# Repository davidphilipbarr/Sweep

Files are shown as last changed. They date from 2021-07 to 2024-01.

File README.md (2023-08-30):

# Sweep
<!--
           ___                        ___
      ___ |   | ___ ___      ___ ___ |   | ___
 ___ |   |`___`|   |   |    |   |   |`___`|   | ___
|   |`___`|   |`___`___`    `___`___`|   |`___`|   |
`___`|   |`___`|   |   |    |   |   |`___`|   |`___`
|   |`___`|   |`___`___`    `___`___`|   |`___`|   |
`___`|   |`___`|   |   |    |   |   |`___`|   |`___`
|   |`___`     `___`___`    `___`___`     `___`|   |
`___`           ___ ___      ___ ___           `___`
               |   |   |    |   |   |
               `___`___`    `___`___`
-->
>  sweep-hero  
> <sub>Bluetooth Sweep 2 + MBK Legend Keycaps</sub>

<span>
  <a href="https://discord.gg/czXcTXbsgU">
    
  </a>
  
  
  
</span>

## What is sweep?

Sweep is a version of the more fabulous [Ferris](https://github.com/pierrechevalier83/ferris) by [Pierre Chevalier](https://github.com/pierrechevalier83/) that uses a daughter board like a promicro, elite-c, bit-c, nice!nano etc. instead of using onboard components.

## What are the different types?

⭐ Sweep 2 - Recommended Choc v1 board with all the features.  
⭕ Sweep Half Swept - Same as Sweep 2, but with a reversible pro-micro footprint.  
⭕ Sweep Bling MX - An MX only Sweep that features Kailh's hotswap sockets and a stacked case.  
⭕ Sweep Bling LP - A Choc v1 only Sweep that features Kailh's hotswap sockets.  
⭕ Sweep High - Same as the Sweep 2, but trades choc spacing for compatibility with more switches and keycaps.  
⭕ Sweep High M - A soldered MX only Sweep, with a reversible PCB design.  
⭕ Sweep Mini - The only version that supports Choc minis.  

| Device | On/Off Switch<sup>[1]</sup> | Reversible PCB<sup>[2]</sup> | Choc V1 | Choc V2 | Choc Mini | MX & Alps | Choc Spacing<sup>[3]</sup> | Tenting<sup>[4]</sup> | Hot Swap |
| :--- | :---: | :---: | :---: | :---: | :---: | :---: | :---: | :---: | :---: |
| Sweep2.x | ✔ | | ✔ | | | | ✔ | ✔ | Mill-Max (optional) |
| Sweep Bling LP | ✔ | | ✔ | | | | ✔ | ✔ | Kailh (required) |
| Sweep Bling MX | ✔ | ✔ | | | | ⚠<br/><sup>[5]</sup> | | ✔ | Kailh (required) |
| Sweep High | ✔ | | ✔ | ✔ | | ✔ | | ✔ |
| Sweep High M | ✔ | ✔ | | | | MX | | ✔ | |
| Sweep Half Swept  | ✔ | ✔ | ✔ | | | | ✔ | ✔ | Mill-Max (optional) |
| Sweep Mini | | ✔ | | | ✔ | | ✔ | |

> Note: All versions support bluetooth with Nice!Nano

*<sup>[1]</sup> An on/off switch is recommended for bluetooth builds.*  
*<sup>[2]</sup> With a reversible PCB it's easier to make mistakes during assembly, but it allows you to purchase less boards.*  
*<sup>[3]</sup> Choc spaced boards have the switches in a tighter grid. This provides a better final look but is only compatible with some choc keycaps. (e.g. MBK)*  
*<sup>[4]</sup> Supports splitkb's [tenting puck.](https://splitkb.com/products/tenting-puck?_pos=1&_psq=tenting%20&_ss=e&_v=1.0)*  
*<sup>[5]</sup> MX + kailh hotswap ONLY. Alps are NOT supported.*  

## Components list

To build and use a Sweep you will need:

* 1x PCB Kit
* 2x promicro compatible boards or 2 nice!nanos.
* 34 switches of a compatible type (refer to the compatibility table)
* 34 keycaps
* 2x reset switches (optional; [B3U-1000P(M)](https://github.com/davidphilipbarr/Sweep/issues/20))
* Some little rubber feet/bumpers
* 2x power switches (optional if supported; MSK 12C02)
* 1x TRRS (not TRS!) cable (wired build only)
* 2x TRRS Jack [PJ-320A] (wired build only)
* 1 USB Cable (depends on your micro-controller choice)

## How do I make this thing?

<a href="https://www.youtube.com/watch?v=fBPu7AyDtkM" target="_blank">
  
</a>

## Firmware

The firmware can be found [with the Ferris  firmware as part of QMK](https://github.com/qmk/qmk_firmware/tree/master/keyboards/ferris/sweep).

Firmware for zmk and bluemicro_ble is called ["Cradio"](https://zmk.dev/docs/hardware/).

## Who made this?

* [Pierre Chevalier](https://github.com/pierrechevalier83)
* [David Barr](https://github.com/davidphilipbarr)
* [Ibnu Daru Aji](https://github.com/ibnuda/)
* [Duccio](https://github.com/duckyb)

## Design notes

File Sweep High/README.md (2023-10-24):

# Sweep HIGH
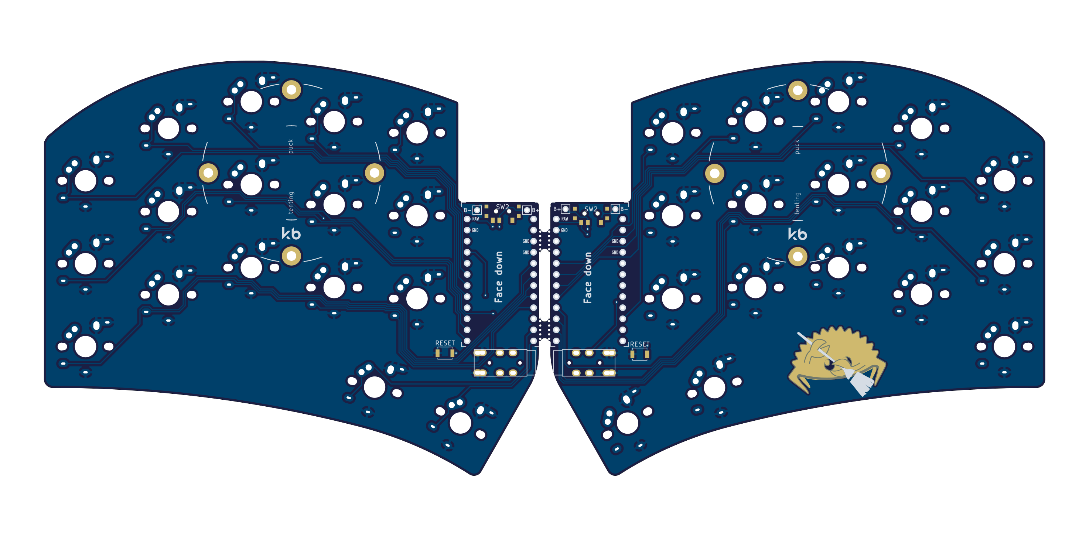
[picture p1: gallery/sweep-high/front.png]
front

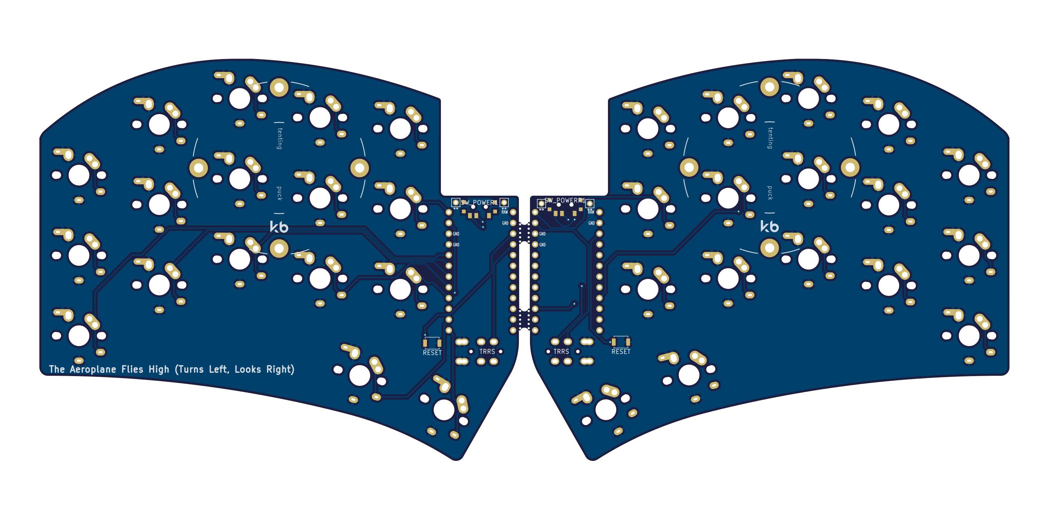
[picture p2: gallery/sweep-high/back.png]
back


Same as the Sweep2 but trades choc spacing for compatibility with more switches and keycaps.

## Ordering The PCB

To order the PCB the following settings are recommended<sup>1,2</sup>: 

|Detail|Value|
|---|---|
|Gerber file|`sweep-high_gerber.zip`|
|Base material|FR-4|
|Layers|2|
|Dimension|95.15mm x 229.54mm|
|Different design|2|
|Delivery format|Panel by customer|
|PCB thickness|1.6mm|
|PCB color|(Personal preference)|
|Silkscreen|(Personal preference)|
|Surface finish|(Personal preference)|
|Outer copper weight|1oz|
|Gold Fingers|No|
|Confirm production file|No|
|Castellated holes|No|
|Remove order number|Yes|

1: Settings are for [JLCPCB](https://jlcpcb.com/), but could work for other manufacturers.

2: Settings are taken from [Kyek's video guide](https://www.youtube.com/watch?v=fBPu7AyDtkM&t=17s).

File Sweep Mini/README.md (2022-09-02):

# Sweep Mini
| Front | Back |
| :---: | :---: |
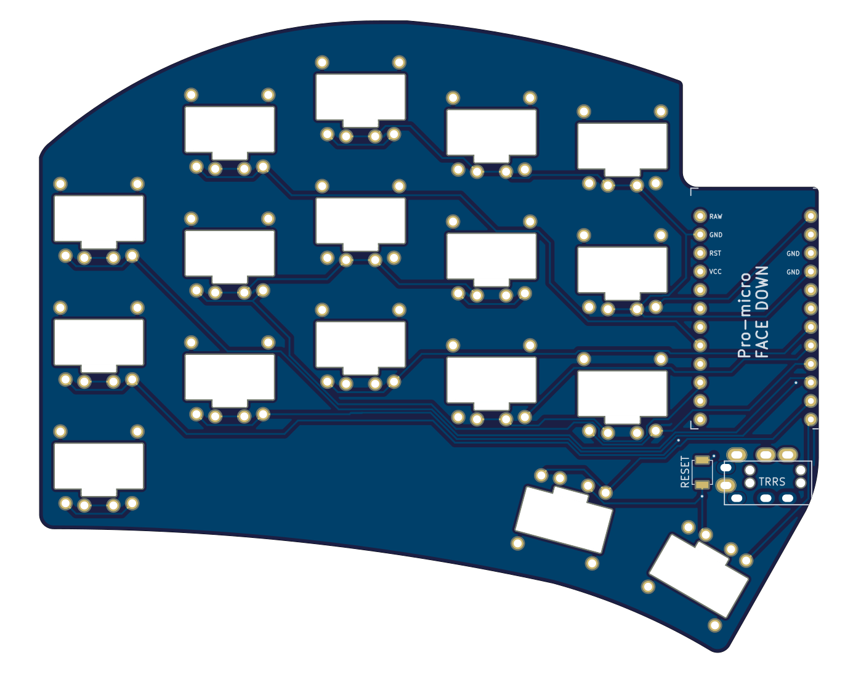
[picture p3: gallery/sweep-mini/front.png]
front
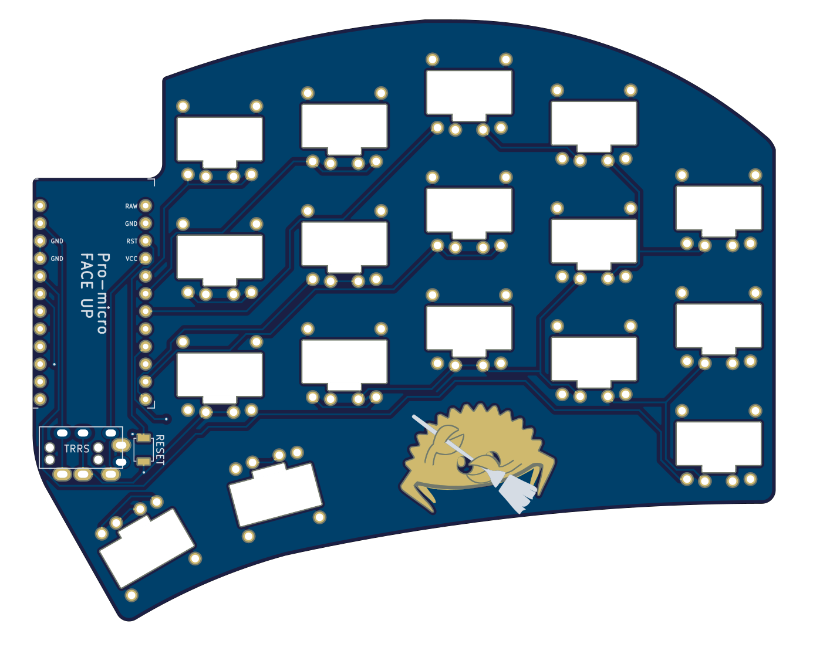
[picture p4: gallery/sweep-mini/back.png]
back
|  |  |

This is the only Sweep version that supports the "Choc Mini" switch.

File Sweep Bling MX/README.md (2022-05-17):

# Sweep Bling MX
| Front | Back |
| :---: | :---: |
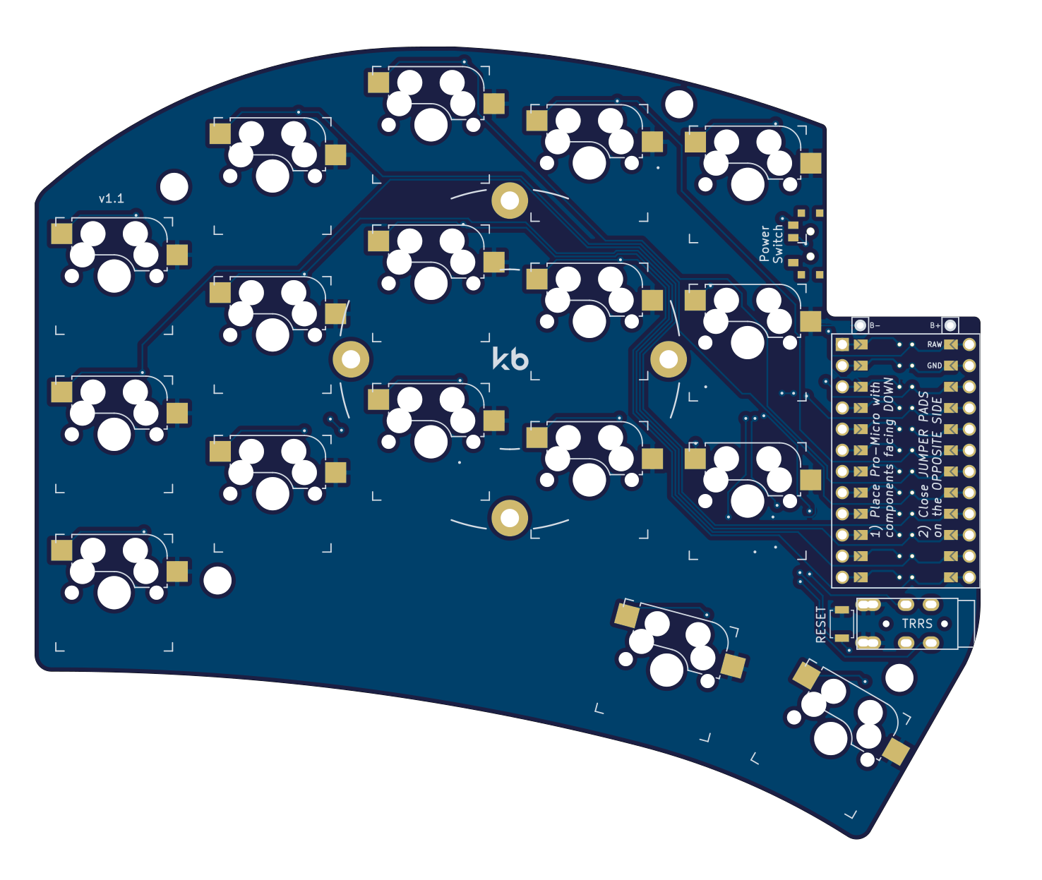
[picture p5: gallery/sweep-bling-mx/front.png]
front
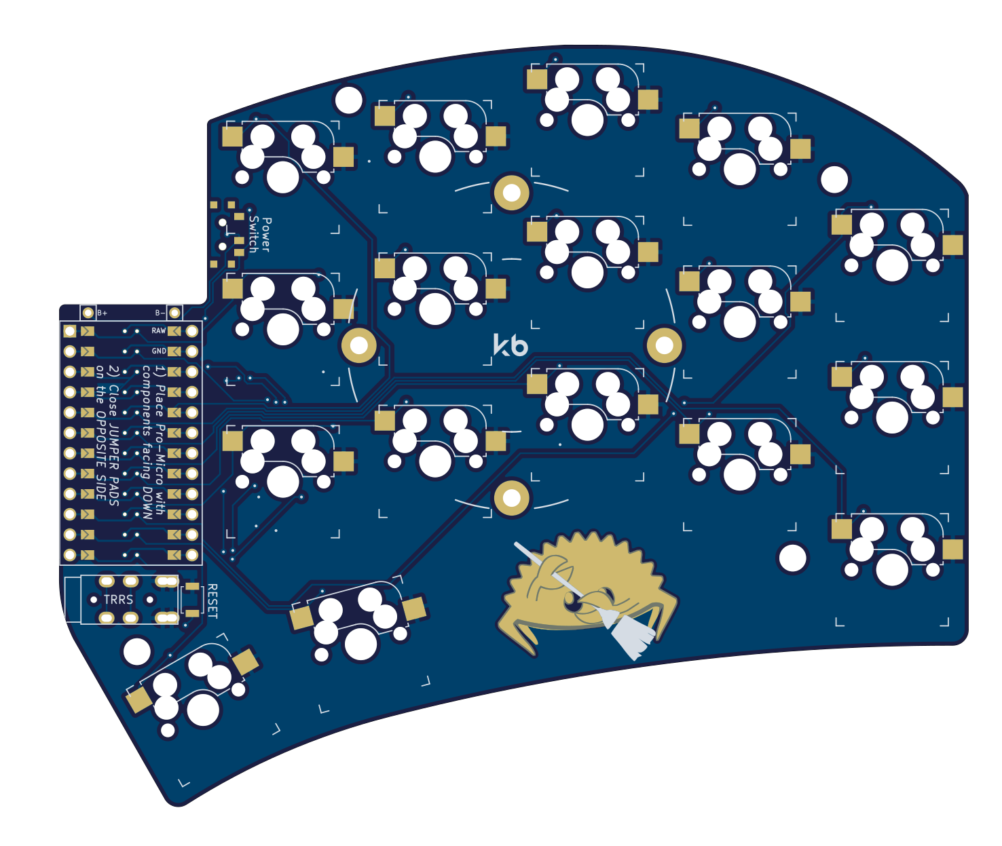
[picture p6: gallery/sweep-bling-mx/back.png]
back
|  |  |
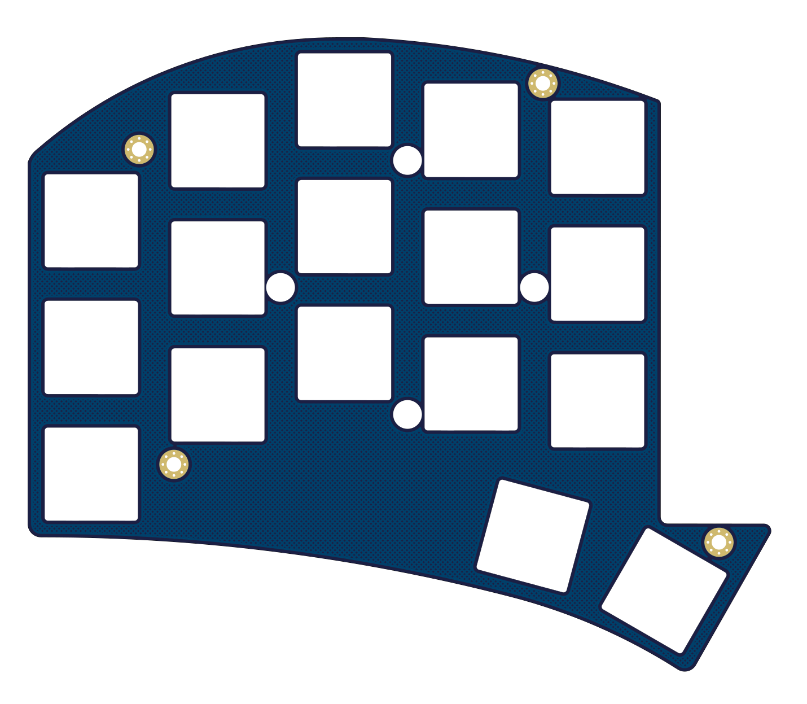
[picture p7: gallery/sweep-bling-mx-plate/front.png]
front
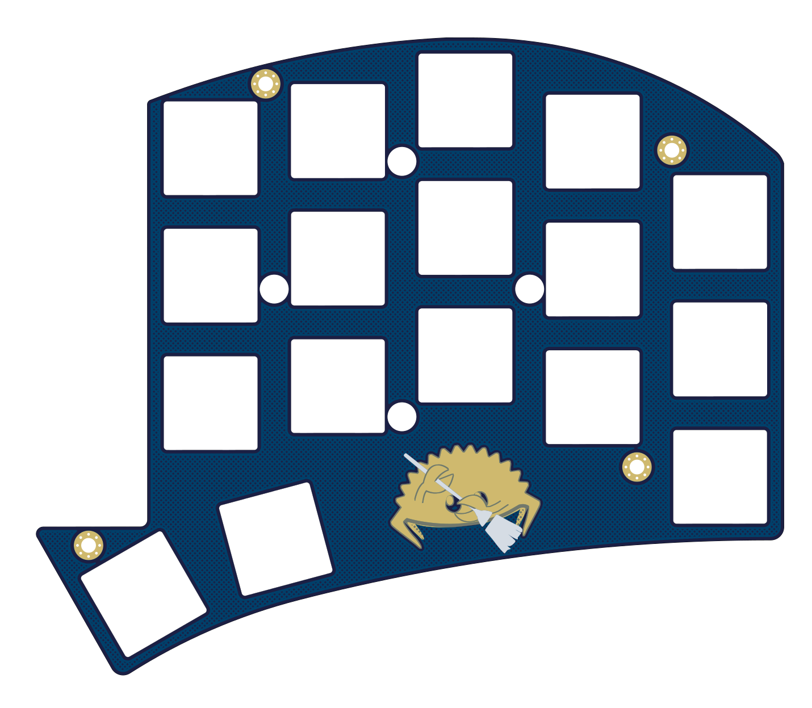
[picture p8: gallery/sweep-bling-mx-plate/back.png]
back
|  |  |
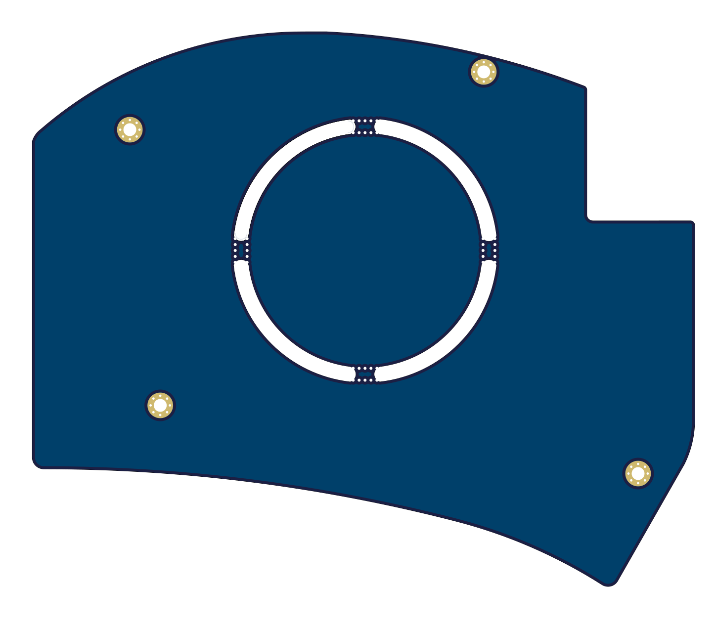
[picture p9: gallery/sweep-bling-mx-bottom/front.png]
front
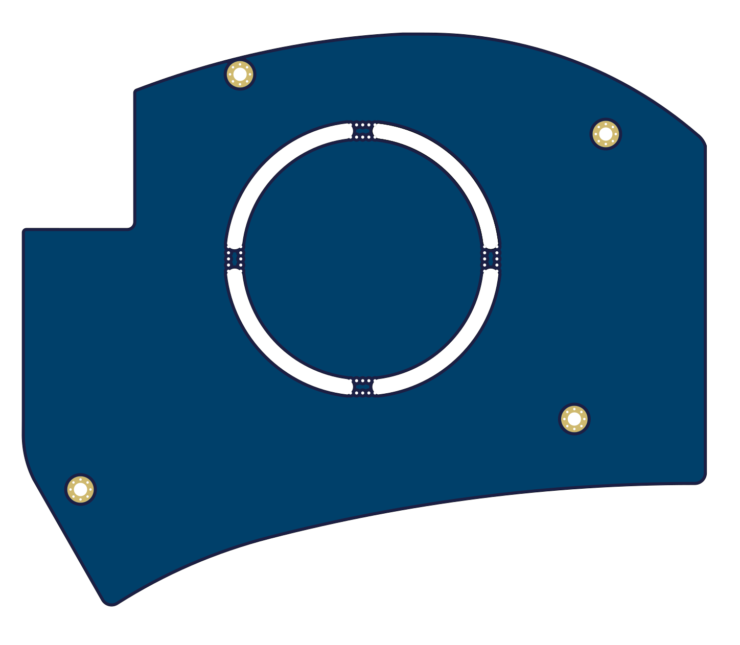
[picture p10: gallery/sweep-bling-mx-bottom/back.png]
back
|  |  |

This version of the Sweep features MX Switches support (exclusively) with hotswap sockets. As well as tenting support.

It also features mouting holes for a stacked case. You can find the switch plate and bottom plate files in the relative folders.

The bottom plate is also compatible with tenting, you can break away the middle section to allow installation of the puck.

## Ordering The PCB

To order the PCB the following settings are recommended<sup>1,2</sup>: 

|Detail|Value|
|---|---|
|Gerber file|`sweep_bling_mx_gerber.zip`|
|Base material|FR-4|
|Layers|2|
|Dimension|95.15mm x 113.47mm|
|Different design|1|
|Delivery format|Single PCB|
|PCB thickness|1.6mm|
|PCB color|(Personal preference)|
|Silkscreen|(Personal preference)|
|Surface finish|(Personal preference)|
|Outer copper weight|1oz|
|Gold Fingers|No|
|Confirm production file|No|
|Castellated holes|No|
|Remove order number|Yes|

1: Settings are for [JLCPCB](https://jlcpcb.com/), but could work for other manufacturers.

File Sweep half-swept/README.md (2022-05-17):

# Sweep Half Swept

| Front | Back |
| --- | --- |
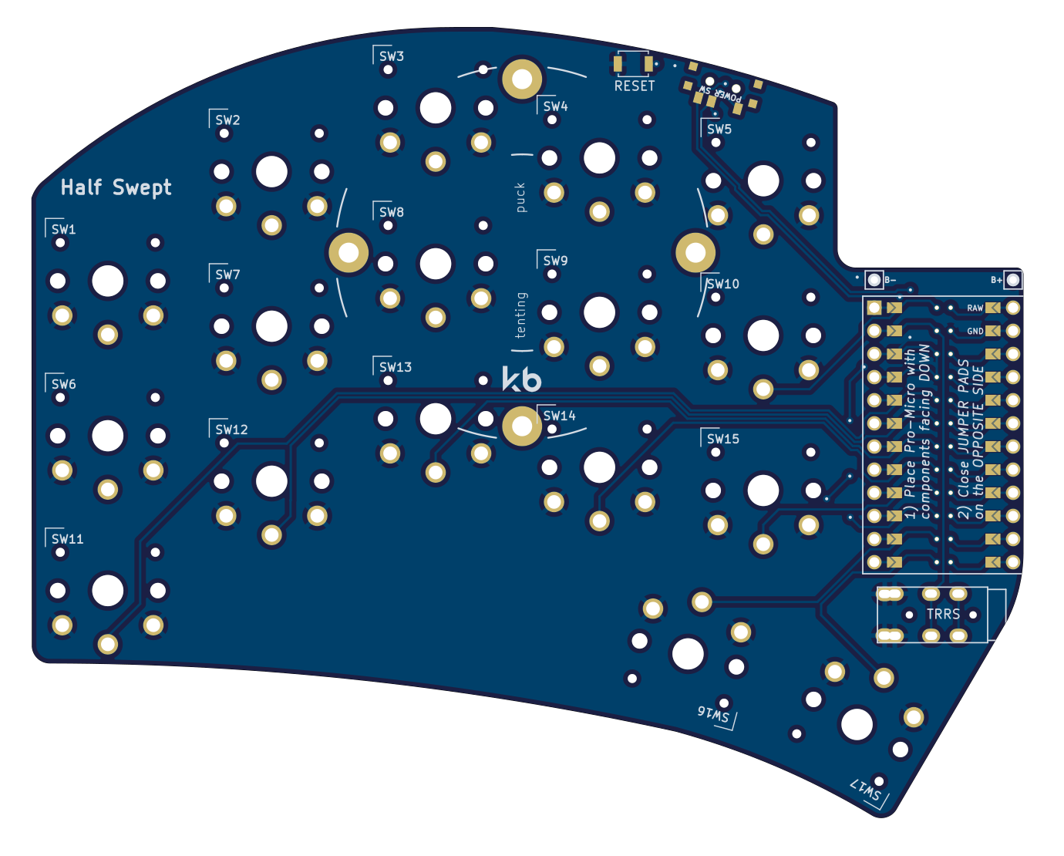
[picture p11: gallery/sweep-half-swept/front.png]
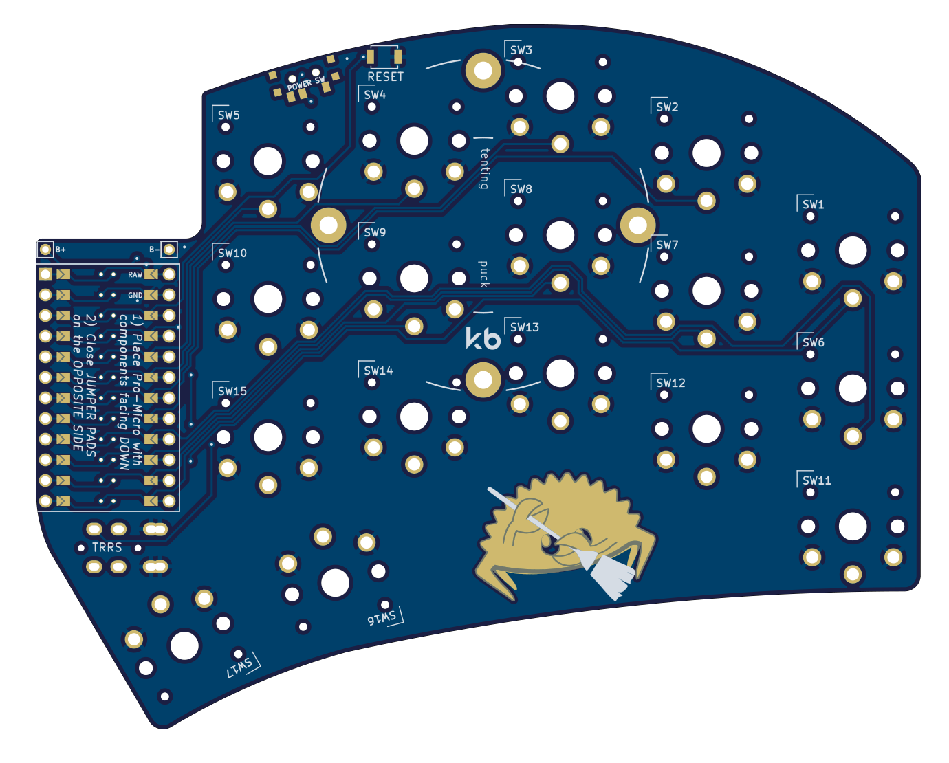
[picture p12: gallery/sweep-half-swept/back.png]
|  |  |

Half of a Sweep2 with a reversible micro-controller footprint.

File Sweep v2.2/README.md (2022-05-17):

# Sweep2
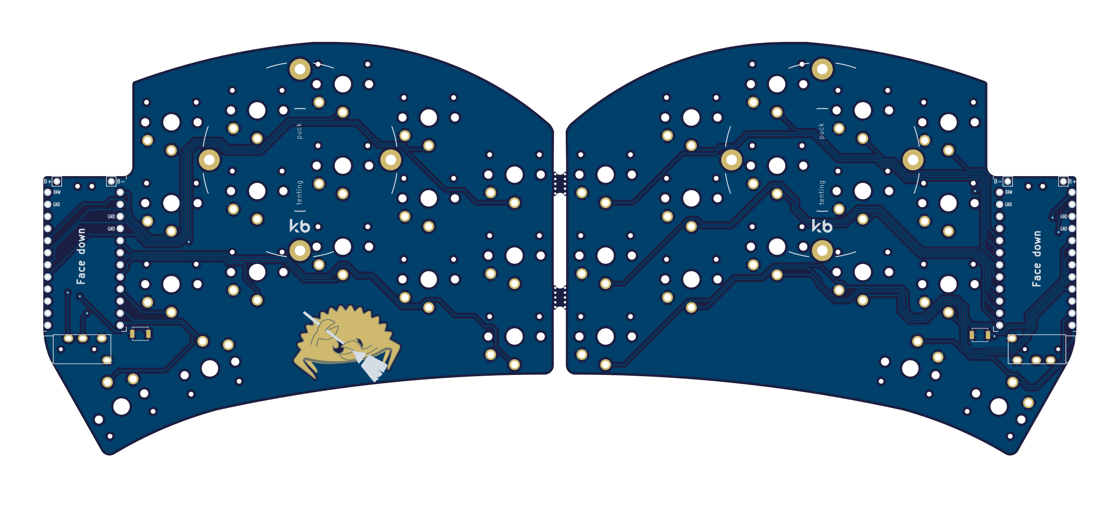
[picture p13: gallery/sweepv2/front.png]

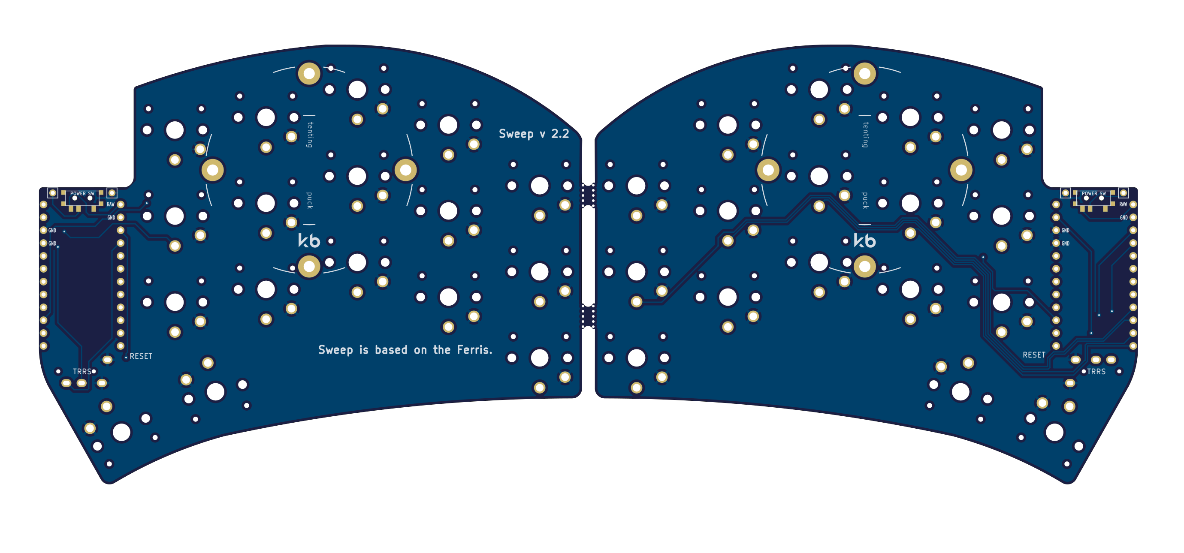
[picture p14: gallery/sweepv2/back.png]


This is the main Choc v1 board we all know and love.

## Ordering The PCB

To order the PCB the following settings are recommended<sup>1,2</sup>: 

|Detail|Value|
|---|---|
|Gerber file|`sweepv2.X_gerber.zip`|
|Base material|FR-4|
|Layers|2|
|Dimension|216.9mm x 86.9mm|
|Different design|2|
|Delivery format|Panel by customer|
|PCB thickness|1.6mm|
|PCB color|(Personal preference)|
|Silkscreen|(Personal preference)|
|Surface finish|(Personal preference)|
|Outer copper weight|1oz|
|Gold Fingers|No|
|Confirm production file|No|
|Castellated holes|No|
|Remove order number|Yes|

1: Settings are for [JLCPCB](https://jlcpcb.com/), but could work for other manufacturers.

2: Settings are taken from [Kyek's video guide](https://www.youtube.com/watch?v=fBPu7AyDtkM&t=17s).

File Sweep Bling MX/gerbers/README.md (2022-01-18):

# Notes:

- **DRILL TIME FEE**: When ordering PCBs with complex shapes like the switch plate and bottom plate, it is possible that the factory will ask for additional fees.

# PCB Hardware Kit (for both sides)
## Required
- 1x PCB Kit
- 2x promicro compatible boards or nice!nanos
- 34 MX switches
- 34 Kailh hotswap sockets
- 34 keycaps

### Optional:
- 2x Battery (required only for wireless; 301230 / 301228)
- 2x Power switches (recommended for wireless; MSK 12C02)
- 2x reset switches ([B3U-1000P(M)](https://github.com/davidphilipbarr/Sweep/issues/20))

# Case Hardware Kit (for both sides)

## Required:  
- 16x M2 Screws
- 8x M2 Spacers. (Max diameter: 3mm, Length: 6-8mm)
- 8-12x Silicone feet stickers

### Optional:
- 2x Splitkb tenting puck
- 2x Manfrotto MP3-BK tripods

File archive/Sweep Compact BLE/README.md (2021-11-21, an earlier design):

# Sweep Compact BLE
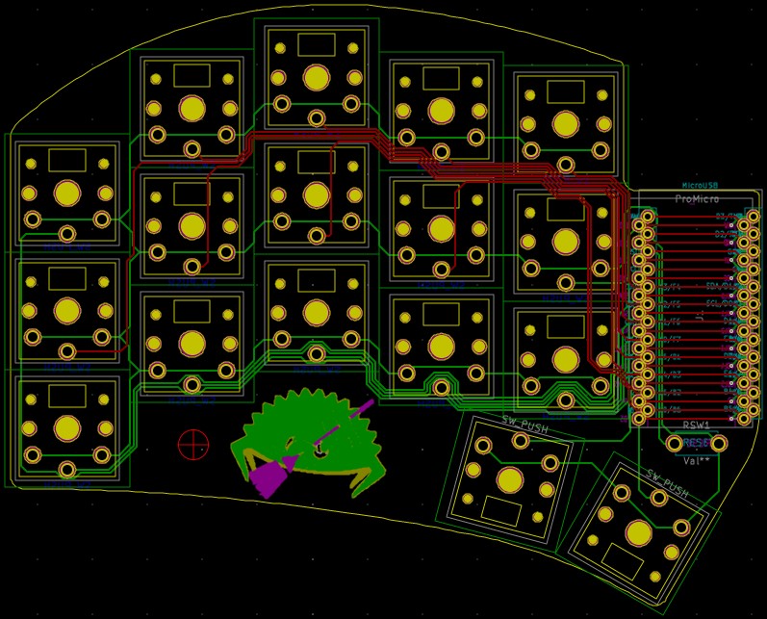
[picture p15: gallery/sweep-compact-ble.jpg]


This is an older revision.  
The Half Swept version is very similar but offers more features.

The main difference in this design is the missing TRRS jack footprint.

## Features

| Device | Bluetooth Support<sup>[1]</sup> | On/Off Switch | Reversible PCB | Choc V1 | Choc V2 | Choc Mini | MX & Alps | Choc Spacing<sup>[2]</sup> | Tenting<sup>[3]</sup> |
| :--- | :---: | :---: | :---: | :---: | :---: | :---: | :---: | :---: | :---: |
| Sweep Compact BLE | ✔ | | ✔ | ✔ | | | | ✔ | |

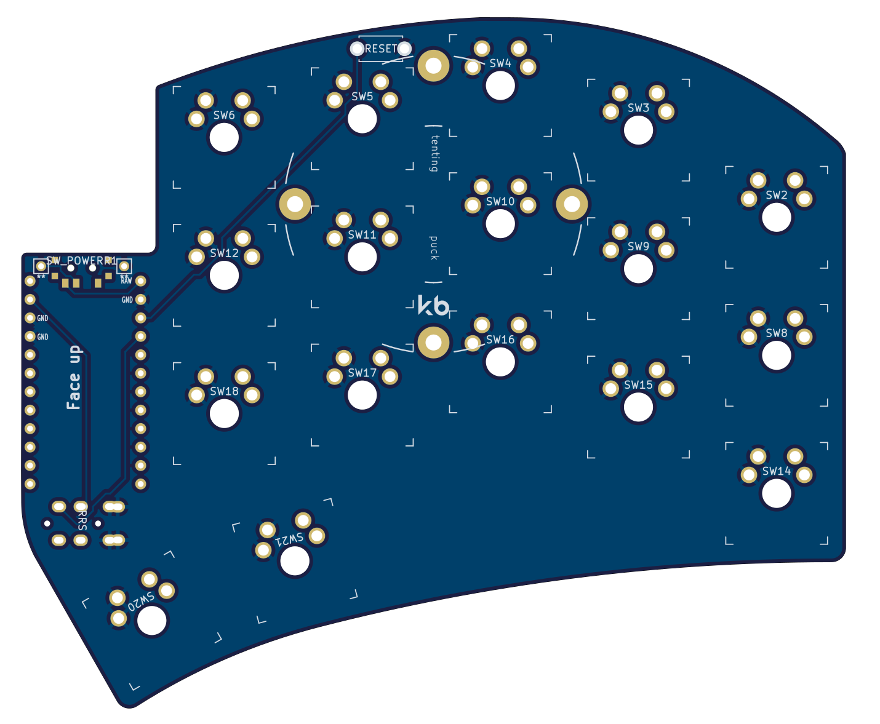
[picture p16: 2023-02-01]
gallery/sweep-high-m/back.png

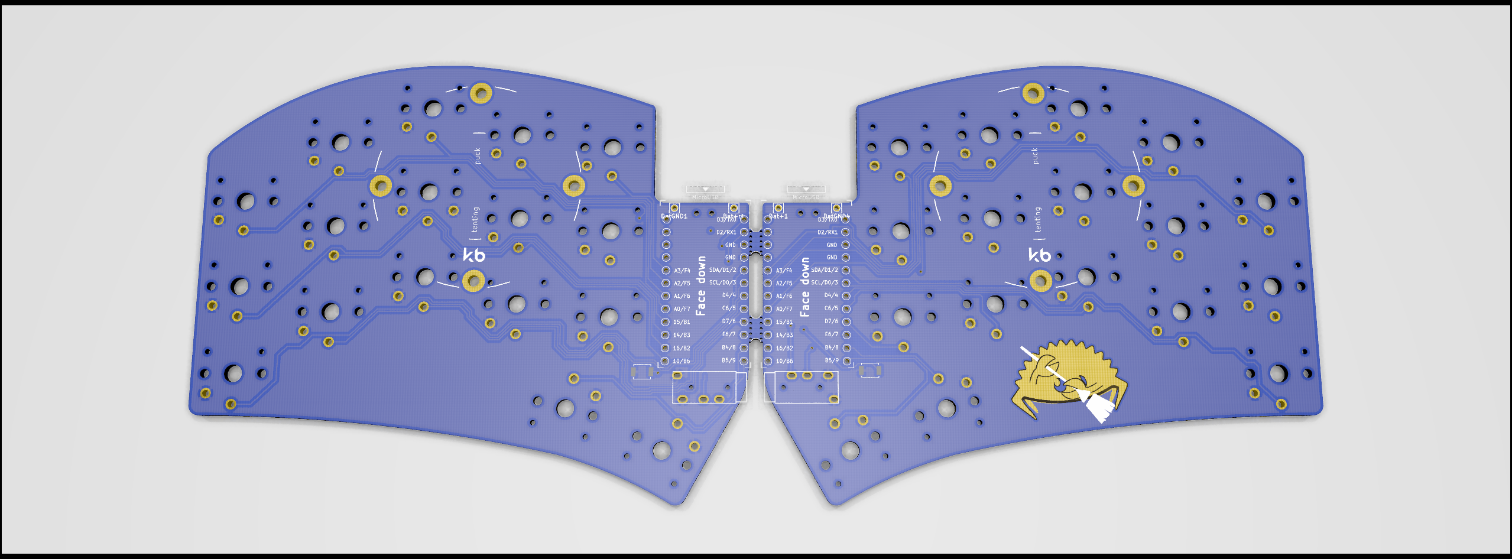
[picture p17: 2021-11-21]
Sweepv2/sweepv2.png

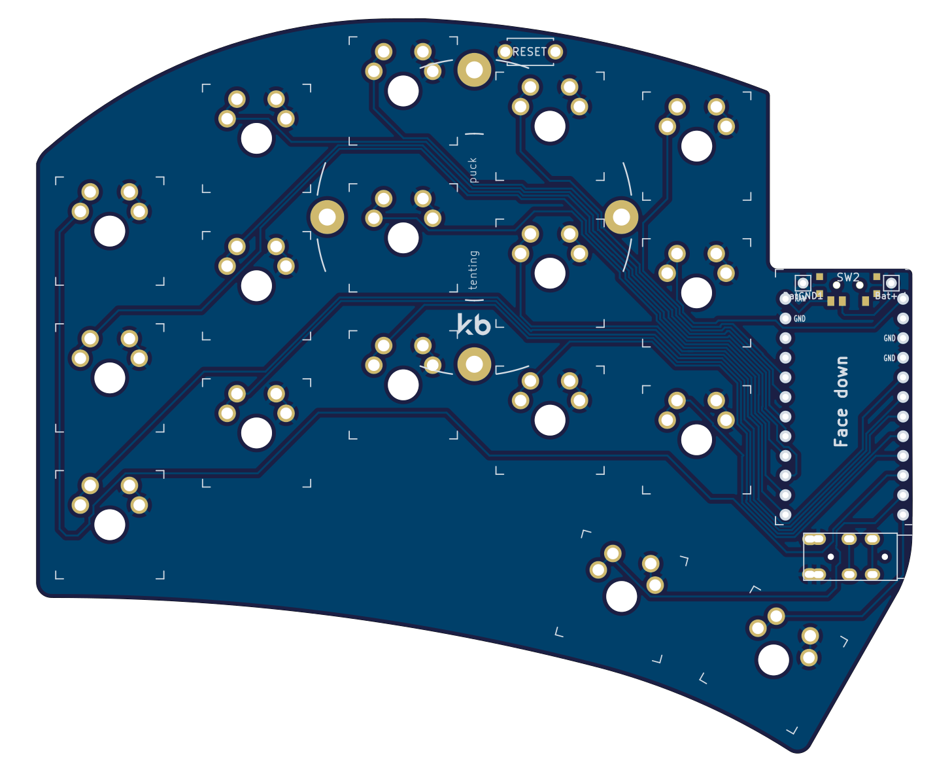
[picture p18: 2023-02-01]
gallery/sweep-high-m/front.png

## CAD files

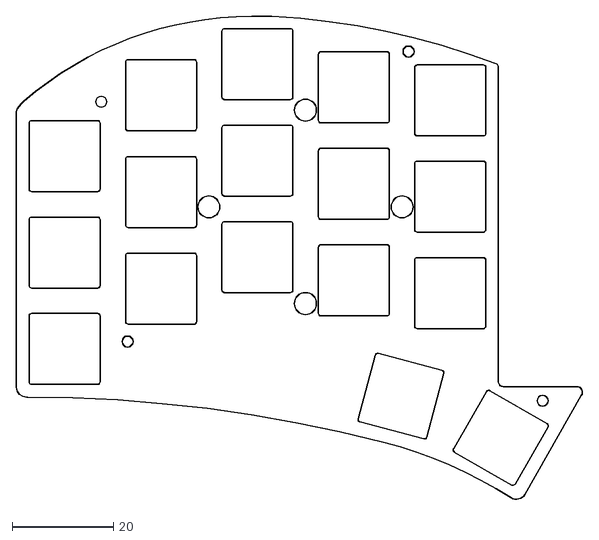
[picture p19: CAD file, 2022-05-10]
Sweep Bling MX/gerbers/sweep-bling-mx__plate-lasercut.dxf
111.6 x 95.2

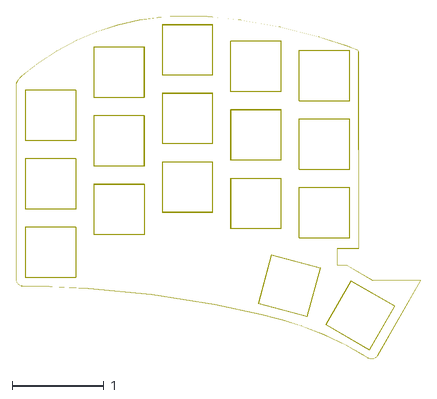
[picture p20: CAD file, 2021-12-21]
Sweep High/sweep-high-top-plate.dxf
4.42 x 3.75

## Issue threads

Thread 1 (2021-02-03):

Schematic and PCB are very different

xphoenixd, 2021-02-03:
Hi, I'm making an MX version of the sweep but the schematic and pcb are very different. The schematic has a matrix and diodes, but the switches on the PCB are direct pin, and with no diodes. I want to submit a PR later, should I edit the schematic to remove the matrix and diodes?

xphoenixd, 2021-02-03:
I'll fix it anyway, it's too different to keep the same.

davidphilipbarr, 2021-02-04:
Yes! The sweep started as a 36 key corne hack and over time I've never
bothered to update the schematic until the on board ble I'm working on,
because I kind of had to :)

It's been something that has kind of grated on me for sometime, and I'm a
little ashamed of, but I am quite lazy.

I also made a mistake in the original which is why the upper pinky (q
normally) does not route very nicely. I've considered changing the pinout
but then I'd have to adjust the firmwares and I don't want to.

I'd love to merge the new schematic if possible!

Thanks

David

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

Closed 2021-02-03.

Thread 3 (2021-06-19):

feature request: choc V2 supported board

deggers, 2021-06-19:
Hey,
Thank you soo much for your work creating a proMicro compatible ferris :)

I wonder if you have any plans in creating a sweep V2 with mx spacing and choc V2 support? The corne light looks sooo cool with mt3 on the choc V2 - but I love the ferris layout .. what do you think?

davidphilipbarr, 2021-09-10:
i nearly have an mx spaced  board ready, i'm just finalising the footprint. mx/chocv1/chocv2 any others? alps?

amcguire2, 2021-09-12:
> i nearly have an mx spaced board ready, i'm just finalising the footprint. mx/chocv1/chocv2 any others? alps?

Thank you for working on this, I can't wait !

bazitov, 2021-09-25:
> i nearly have an mx spaced board ready, i'm just finalising the footprint. mx/chocv1/chocv2 any others? alps?

How do you look at the idea to have the hotswap and none-hotswap choc PCB like Architeuthis dux?

duckyb, 2021-12-21:
This issue was solved with the introduction of the **Sweep High**, it should be closed.

Closed 2022-01-01.

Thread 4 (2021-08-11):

[Sweep v2] MCU pads very close to keyboard edge

duckyb, 2021-08-11:
Hi, I printed the latest version of the Sweep v2 from JLCPCB and I noticed a small issue with the design.
First of all, the fact that the PCBs are conjoined leaves two small bumps on the inner edge of the board, which can be sanded but might be risky with it being so close to the MCU's pads.
And second, the pads are very very close to the edge, nothing to worry about but it would be nice to have a slight margin between the MCU's pads and the edge of the PCB.

Both these issues could be fixed by adding a .5mm - 1mm margin to the inner edge of the PCB.

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

davidphilipbarr, 2021-09-10:
I think this fixed in the dev branch, the holes are very close to the edge still, but less so.
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

duckyb, 2021-09-10:
It should be enough!

Closed 2021-09-10.

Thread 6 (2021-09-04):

PCB Questions

kmplngj, 2021-09-04:
Hello,

I ordered some free Sweep-half-swept PCBs. Now Allpcb has some question to the files. Could you help me with this?

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

Thanks a lot

davidphilipbarr, 2021-09-04:
I've asked someone who got this printed at allpcb what they said. Off the
top of my head i think the first one can be left as pth and second is the
'crab' so I'd suggest leaving as is. If you sit tight I can get some
answers from someone with a working PCB from allpcb!

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

kmplngj, 2021-09-10:
I even got one more question. Perhaps someone owns if this needs to be fixed.

_Is the broken line pointed by the arrow normal?_
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

davidphilipbarr, 2021-09-10:
Hi! sorry for delay. that last trace shouldn't be there, but it's not doing any harm either! (i'll fix it)
No one else seems to have had any issues with allpcb, so i'd just suggest proceeding 'as is'

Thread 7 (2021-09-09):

Misaligned Silkscreen bottum side writing for MCU (Minor Issue)

eXsoR65, 2021-09-09:
Don't know how to use KiCad otherwise I would fix it 😄

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

davidphilipbarr, 2021-09-10:
I think this fixed in the dev branch

Closed 2021-11-24.

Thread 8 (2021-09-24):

KLE json keymap file for Sweep34

humky, 2021-09-24:
I want to 3d print Sweep34 plates for handwired build. I usually use KLE (keyboard-layout-editor.com) and keyboardcad.com to produce the stl files for printing, but I can't find Sweep or Ferris KLE keymaps anywhere. (which is logical since it's PCB based boards) still, does anyone here have a KLE map for either Ferris or Sweep (I will surely mess up the angle of the keys or their placement if I try to reproduce it manually at KLE)

davidphilipbarr, 2021-09-26:
I know there is a ferris one, but I don't have a link to it. possibly your
best bet is to delete the keys you don't need from the kyria one?

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

humky, 2021-09-27:
I've been printing  and testing different plates for the past few days, and turns out I don't really need the arch on the bottom row that much. I'm equally comfortable with it being the straight row, maybe cuz I've been using Planck style keyboard for the past year or so. Anyway, here is my current board, I'm finalizing pinkey column stagger, all others pretty much perfect for my hands.

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

Closed 2021-09-27.

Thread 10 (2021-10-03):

feature request: back plate and switch plate filess

paulrobshannon, 2021-10-03:
Would it be possible to add additional M2 holes in the PCB for mounting a back plate as well as adding the back plate files w/puck footprint and a switch plate file?

Would be great for some laser cut brass for weight & protection.

im3shn, 2024-12-31:
is this added guys?

im3shn, 2024-12-31:
I just need a back plate, how to find that, can anyone help?
\

duckyb, 2025-07-21:
Switch plates are only available for the MX versions and can be found inside the Sweep Bling MX folder.

priyanshoon, 2025-07-23:
dimensions for  sweep-bling-mx__plate.dxf is wrong

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

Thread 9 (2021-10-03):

https://jlcpcb.com won't print Sweep V2

danpassmore, 2021-10-03:
Hi, love this design, but when I attempted to print the Sweep V2 using https://jlcpcb.com, they wouldn't print the board for the following stated reason:

Quote:
Hi there,so sorry that the width of the breakaway tabs is too small which may cause board breaking off very easily.Please kindly increase it to 4mm at least.You can click "replace file" button to re-upload the updated gerber file in your account.Thanks.

Have you ever successfully used jlcpcb to print the Sweep V2?
Is what they're suggesting a reasonable request?

danpassmore, 2021-10-03:
Okay, I was able to work around their audit rejection by specifying the PCB material FR4 instead of Aluminum.  Seems something about printing in aluminum puts more stringent constraints on the breakaway tab width.

(I've never ordered a custom pcb before, so not sure if aluminum is a good idea or not, but my thought process was that it might result in a nicer/sturdier keyboard, and it was even a dollar cheaper than FR4!  Oh well.)

vogler, 2022-02-10:
> (I've never ordered a custom pcb before, so not sure if aluminum is a good idea or not, but my thought process was that it might result in a nicer/sturdier keyboard, and it was even a dollar cheaper than FR4! Oh well.)

Just wondered the same...

Closed 2021-10-03.

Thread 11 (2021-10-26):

Sweep v2 Power Switch Question

danpassmore, 2021-10-26:
Forgive me if this is a silly question:
In the description of the Sweep v2 (re-pasted below), I see it mentioned it supported a power switch:

"Sweep2 - this superceeds the compact and possibly the compact ble, it is compact with power switches and puck support."

... however on my printed board it's not obvious to me where such a "power switch" would go.

First of all, maybe I am misunderstanding what is meant by "power switch"?  I am using nice!nice microcontrollers for their wireless capabilities and I was looking for a switch to go in-between the battery and the microcontroller that would fully disconnect the battery when I desired, such that if a key is accidentally pressed (e.g. during transport) the keyboard doesn't drain battery.  Looking at the printed board (and testing connections with my multimeter), I don't see anything on the board that would help me achieve that goal.

I do see (on both hand-sides, next to the TRRS pad) a narrowly separated set of surface pads where one pad connects to the microcontrollers reset pin, and the other goes to ground.  To me, it seems like if a surface mounted switch was placed on these pads, you could use the switch to connect the reset to ground to reset the microcontroller.  Is this what was meant by a power switch?  Unless I'm missing something, I don't see how that could be used to achieve my goals, right?

danpassmore, 2021-11-01:
Closing issue as all questions have been answered.

Closed 2021-11-01.

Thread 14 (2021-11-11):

What are the differences between Sweep v2 , Sweep-half-swept and Sweep-Compact?

IronArthur, 2021-11-11:
I´m trying to decide what Sweep to build. My ultimate goal would be that at least the left board is wireless when nice!nanos are available. At first i will use some pro micros.

I'm having trouble finding the differences between those 3 pcbs, especially i can´t find what are the differences of the half-sweet

Sweep v2: has wireless capactity with holes for the battery? and on-off button i think
Sweep-half-swept: the same as v2 but the pcb is cheaper because it is smaller (8€ cheaper on jlpcb). Cons: right board has pro micro upside down? you end with 2 and half kits of pcbs (instead of 5 PCBs in V2)
Sweep-compact: cheaper pcb as the previous one, but no battery holes and no tenting??

If i understand everything, there is no point of using the compact when the half-swept exists, but maybe there are some other differences that I am not aware of.

duckyb, 2021-11-11:
A few facts that may clear some things up:
- All versions support wireless. If there are no battery pads you simply connect the red wire to RAW and the black wire to GND on the micro controller. The battery pads are just extensions of those pins.
- If you want to build a wireless board both sides must use a nice!nano
- Contrary to the sweep compact, the half swept has a double micro-controller footprint, letting you install both daughter-booards facing the same way. (both with components facing up / down)

| Device | Bluetooth Support<sup>[1]</sup> | On/Off Switch | Reversible PCB | Choc V1 | Choc V2 | Choc Mini | MX & Alps | Choc Spacing<sup>[2]</sup> | Tenting<sup>[3]</sup> |
| :--- | :---: | :---: | :---: | :---: | :---: | :---: | :---: | :---: | :---: |
| Sweep2            | ✔ | ✔ |   | ✔ |   |   |   | ✔ | ✔ |
| Sweep Half Swept     | ✔ | ✔ | ✔ | ✔ |   |   |   | ✔ | ✔ |
| Sweep Compact     | ✔ |   | ✔ | ✔ |   |   |   | ✔ |   |

IronArthur, 2021-11-11:
Thanks for the fast answer!

I thought that for wireless connection you could connect wirelessly to computer (instead of USB cable) and connect with trrs to the other board. So if I understand correctly, both boards connect independently to the computer? Good to know.

On kicad i´ve seen that the Half Swept has a couple of holes on the topside of the pcb (reset + gnd) that v2 doesn´t have, what are those ( on/off switch relocated?)
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

I still don´t get what´s the point of the compact when the half-Swept exists.

duckyb, 2021-11-11:
> So if I understand correctly, both boards connect independently to the computer?

Yes.

> what are those

I have no idea.

> I still don´t get what´s the point of the compact when the half-Swept exists

@davidphilipbarr doesn't like to delete old stuff! The only dis-advantage is that the half-swept is marginally wider because of the double footprint

kuroahna, 2021-11-11:
@duckyb Thank you for the very helpful information! It'd be great if we can update the README with it.

Also, I'd like to double check, but if I want to build a wired Sweep Half Swept instead of Sweep v2 from AllPCB, will your video still apply? https://www.youtube.com/watch?v=fBPu7AyDtkM

I'm looking to use:
1. [2x Elite-C Low Profile v4 microcontroller](https://splitkb.com/collections/keyboard-parts/products/elite-c-low-profile-rev4-microcontroller) installing both face down on the half swept
2. [4x Mill Max Low Profile Sockets with 48 Mill Max Pins)(https://splitkb.com/products/mill-max-low-profile-sockets?variant=31945995845709)
3. 2x Reset switch
4. 2x TRRS Jack
5. 34 PurpZ switches
6. 34 keycaps
7. Rubber feet

duckyb, 2021-11-11:
@kuroahna I already updated the readme in #15.

Yes you can still follow the video with your half swept board. Only thing that I have to warn you about is that the Purpz might be a very tight fit in the PCB because of different tolerances. (I never used them but I've read some discord messages where a user had some problems installing purpz on a sweep)

With that being said, please only use the issues page to discuss problems with this project or request new features! If you have questions about my tutorial or need help with your build, the youtube comments or the discord server are a better place to ask.

IronArthur, 2021-11-11:
What's the point of the "Reset switch"?, it´s probably the thing that goes on the holes in the image i've attached, but what's suppose to be? just a button??

duckyb, 2021-11-11:
> What's the point of the "Reset switch"?, it´s probably the thing that goes on the holes in the image i've attached, but what's suppose to be? just a button??

Yes. It's just a small button that shorts GND and RST pins. You can just use tweezers or any other conductive object to short them instead.

IronArthur, 2021-11-15:
Thanks for all the info! i´m waiting for my parts! and the pcb from allpcb free prototype.

Closed 2021-11-15.

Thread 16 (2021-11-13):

Sweep High Gerbers

telepuzikIsmail, 2021-11-13:
There seems to be something wrong with the gerberfiles for the Sweep High.
They dont work on JLCPCB, no preview and so on.. or am I doing something wrong?

duckyb, 2021-11-13:
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

It might be caused by the new footprint that has some overlaps. The lower two overlaps on the drill layer are reported as errors by the DRC tool in Kicad.
If you still order it the JLC team will still check it for you and let you know if there are issues with your order.

Keep in mind this is a new design and I don't even know if it was ever ordered by anyone before

telepuzikIsmail, 2021-11-13:
Thanks for the quick answer.
I have order boards now, I'll let you know if it worked out or not.

Micosilent, 2021-11-15:
I've tried to order Sweep High boards as well, and JLCPCB is complaining about the minimum breakaway tab being 4m
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

duckyb, 2021-11-15:
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
[sweep-high_229x356mm_for_JLCPCB.zip](https://github.com/davidphilipbarr/Sweep/files/7537976/sweep-high_229x356mm_for_JLCPCB.zip)

On 13/11/2021 @davidphilipbarr shared a gerber for JLC that is missing in this repository. I'm reposting it here for people that might be interested in it.

telepuzikIsmail, 2021-11-15:
This is what they wrote me in the first mail:

> Sorry that the minimum width of breakaway tab with mouse-bites we recommend is 5mm.
> Sorry that the minimum width of breakaway tab we recommend is 4mm.
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

After replacing the gerbers with those from the post above they wrote:

> the spacing from slot to slot and slot to board edge are too small which will cause the board broken easily,please kindly increase it to 4mm at least.
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

Micosilent, 2021-11-15:
The thing is that we literally want the board to break, so the two halves come apart. If you want to wait until I receive mine, I have placed the order and told them to disregard the <4mm breakaway, and will update when the order arrives.

Otherwise just tell them to go ahead with the fab

duckyb, 2021-11-15:
@Micosilent @telepuzikIsmail the mouse bite footprint is the same used on the Sweep2 PCB and there are no issues with that one. I ordered them before and they didn't ask me anything and the PCBs were ok.

I guess they just want to complain more this week.

Micosilent, 2021-11-15:
JLCPCB is refusing to make the pcbs with the small mouse bites 😞

telepuzikIsmail, 2021-11-16:
I wrote them to go ahead and make the pcbs the way they are now and they decided not to answer me so I canceled the order...
I'll try to edit the pcb this weekend and try again.

duckyb, 2021-11-16:
@telepuzikIsmail @Micosilent I tried to do it for you.

| Current version | My updated fork |
| --- | --- |
| 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 | 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 |
| 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 | 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 |

My fork gerber: [sweep-high-gerber.zip](https://github.com/davidphilipbarr/Sweep/files/7546704/sweep-high-gerber.zip)

Please note that I removed the GND-GND wire that crossed the mouse bite, as it didn't fit through the drill holes. But I don't think it is important as it will be broken off.

Also note that this gerber does not show a preview on JLCPCB, just like the gerber from the current version in this repo.

microfortnight, 2021-11-18:
JLCPCB accepted my order based on the fork of @duckyb
Didn't use the linked gerbers because I wanted to remove the crab 😜
I used asukiaaa/gerber_to_order to create the gerbers and the preview on JLCPCB is displayed correctly.

duckyb, 2021-11-18:
@microfortnight thank you for the feedback! If you could update us once more after receiving the PCBs it would be awesome.
In particular regarding the breakaway tab; if it snaps well, how much clean up is required, possible improvements, etc.

Also nice tip on using that gerber tool. I'll check it out!

nodupe, 2021-11-18:
I’ve placed the order a few days ago and had the same issue, even after assuring them it was supposed to break, they still complained. Just uploaded the new file now, looking forward to their answer.

Narice, 2021-11-30:
@microfortnight, did you get the board? I'll probably build one and having some feedback to know if this gerber file worked would be really awesome :grin:

microfortnight, 2021-12-08:
@duckyb PCBs look fine, didn't build the board yet.
Seperating the halves is easy, one half can be broken up by hand, you will need pliers to separate the tabs from the other half. That's a very minor disadvantage, compared e.g. to the crkbd cherry, where it's possibe to do it using hands only.
Apply a very light sanding and it is good to go :+1:

lxhan, 2021-12-11:
Hey guys, can someone please explain or show how to plug in switches into sweep high board? I've just received pcb but wanted to double check before soldering, is it ok that mx switches are loose compared to what I saw in @duckyb video on youtube or something wrong with my board?

duckyb, 2021-12-11:
@lxhan Yes it's somewhat normal. But make sure that you are using 5 pin switches (PCB mount)

Narice, 2021-12-11:
@microfortnight thanks! that really helps

Closed 2021-11-19.

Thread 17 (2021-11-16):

sweep 2.1 gerbers

mybigman, 2021-11-16:
gerber zip is missing for 2.1 or do we use the one from 2

thanks

Micosilent, 2021-11-16:
2.1 is Work in Progress, you can use the gerbers from v2  though :D

duckyb, 2021-11-23:
The gerber for 2.1 is available if you want to try it!

eXsoR65, 2021-11-29:
@duckyb looks like the gerber file is not reflecting the change of removing the extra pin on one of the switched on the right half. I tried to generate the gerber files but gave me a warning about filling in. But I'm new to this so not sure if I should or not. Any help on this is appreciated.

duckyb, 2021-11-29:
@eXsoR65 you can find the updated files on my branch https://github.com/duckyb/Sweep/tree/update-gerbers
I also created #24 to update them here.

eXsoR65, 2021-12-02:
@mybigman Issue was address so you can close the issue. see PR #24

Closed 2022-01-01.

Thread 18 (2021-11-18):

Sweep 2.1 Changes/Goals

defiant00, 2021-11-18:
Hi, just wondering if there's a specific issue (or design goal) that the Sweep 2.1 is meant to address?

duckyb, 2021-11-18:
I can see these differences:

## v2.1 - Changelog
- Better alignment of the micro-controller footprint silkscreen
- Change micro-controller silkscreen from full labeling to minimal
- Move micro-controller footprint away from edge cut (~0.13 mm)
- Connect the two PCBs with mouse-bites away from the micro-controller footprint

defiant00, 2021-11-18:
Thanks so much for the info, that's quite helpful!

Closed 2021-11-18.

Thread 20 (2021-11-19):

Reset switch part number

ch604, 2021-11-19:
From the images they appear to be SMD 3x4x2 2 pin pushbuttons, correct?

duckyb, 2021-11-23:
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

Documentation: https://omronfs.omron.com/en_US/ecb/products/pdf/en-b3u.pdf

This component is compatible. Part number is **B3U-1000P(M)**
(this is just one of many compatible buttons)

duckyb, 2021-11-23:
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

This is the footprint, for reference

ch604, 2021-11-23:
Thanks for that pcb breakout and the exact reference part, looks like the piece I selected will fit!

Closed 2021-11-23.

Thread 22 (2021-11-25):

Sweep 2.1 has 2 designs?

paulchiu, 2021-11-25:
First of all, thanks for the great work on the Sweep, I discovered this project through Ben Vallack's YT video.

Not sure if this is the right place to ask, so feel free to close.

I have placed an order with JLCPCB with the 2.1 Gerber file and received this message from them:

> You need to pay additional for your order.
>
> 1.The order info shows that there is only one design , but actually, there are 2 different designs in your file, so there will be an extra cost for it if you want to make it as show in your file.Please kindly choose the correct designs when you place your order next time.

I set my order details based on settings recommended by the Kyek video; although I did deviate by using the 2.1 file.

I noticed that https://github.com/davidphilipbarr/Sweep/issues/17#issuecomment-970198629 mentioned that 2.1 is still WIP, so my question is will my order produce a functional PCB or do I need to make another order with the v2 Gerber file?

I wasn't sure what I was looking at with the zip file in Kikad, but upon closer inspection, the only thing I can see that seems like a secondary design is the `sweepv2.1_plate` file, is that what JLCPCB would be referring to?

davidphilipbarr, 2021-11-25:
It's probably just because it has detected the two slides, so it's saying
there are two boards in one design, which is true.
JLC can be a bit weird and inconsistent about this kind of thing,
usually the extra charge is small though.
The 2.0 had a trace joining the halves, so it might avoid this warning. If
in doubt i'd use the 2.0 as it's been more tested, but it should be fine
and the warning from jlc is to be expected really.

hope that helps!

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

duckyb, 2021-11-25:
The v2 also doesn't have this trace, I removed them with the new breakaway tabs. If this trace is needed the breakaway tab footprint needs to be updated.

paulchiu, 2021-11-25:
Thanks for the quick clarification guys.

> usually the extra charge is small though.

Yes, it was only like $5 AUD so I just paid it as soon as I got the email, just wanted to confirm here that the design was ready for use; thanks for confirming that it is.

> If you don't want to wait for an update or pay the extra cost you can order the half-swept version instead, which is just one design.

It's not a big deal really.

> the warning from jlc is to be expected really.

Do you mind if I do a PR for the 2.1 README with the information you guys provided in this issue?

Closed 2021-11-30.

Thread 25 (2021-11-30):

Sweep High Half-Swept

hadaad, 2021-11-30:
Do you think it would be possible to create a half-swept sweep high?

duckyb, 2021-11-30:
I think the naming system should be revised 😂

athul, 2021-12-01:
Would be great if you could make this. It's relatively hard to get my hands on choc switches but it's really easy to get mx type switches😅😅

duckyb, 2022-01-01:
Well, it exists and it's called **Sweep High M**

Closed 2022-01-01.

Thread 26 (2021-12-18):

Daughter board silk screen for half-swept inverted

bowlerhatman, 2021-12-18:
Hi there, it appears the silk screening for the daughter board on the half swept is inverted, i.e. the indication for which rows of holes should be used for each side is backwards. This leads to VCC being shorted to reset if you follow the visual indication. Can I suggest clarifying the silk screening, or alternatively removing it and providing written and visual instruction? As a side note, the row of holes closest to the board edge is *very* close to the edge. Suggest moving the edge.cut out to the other graphical edge line.

Happy to do this, but am not up to speed with git. Fine with kicad though.

Closed 2021-12-21.

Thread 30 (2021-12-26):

Question: Difference between High and High M

isavcic, 2021-12-26:
Hello,

I apologize if this question is an obvious one, but I'm about to embark on building an MX-version board for myself. Which version of High should I use? What is the difference?

Thanks!

duckyb, 2021-12-26:
High M is the reversible version of the high. Like sweep2 vs sweep half swept.
You can use both but the high is more tested

isavcic, 2021-12-26:
In which way "reversible", as in the board can be on the bottom side of the board?

duckyb, 2021-12-26:
@isavcic yes. Reversible means that the same PCB is used for left and right side. In the regular sweep high you have a dedicated PCB for each side.
This is just a minor difference, both devices function the same.

isavcic, 2021-12-26:
@duckyb Thanks!

Closed 2021-12-26.

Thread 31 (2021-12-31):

Comaptibility with Pro Micro with USB-C port?

Sono-Gomorrha, 2021-12-31:
I was wondering if the 2.1 PCB would be compatible with Pro Micros with USB C port or only with Micro USB.
I know this might sound stupid, but I am somewhat new to building these and some of the listings I saw the USB C version is listed longer (2mm difference) and the spacing / sizing of the pinholes looks a little different.

This is an [example](https://www.aliexpress.com/item/32768308647.html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) and here is [another](https://www.aliexpress.com/item/1005001621886380.html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).

duckyb, 2021-12-31:
It's compatible

Closed 2022-01-02.

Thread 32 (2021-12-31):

3D printable top plate for the Sweep High?

mrtnee, 2021-12-31:
Hi, how would one go about creating the 3d printable file for the plate? I know there is an .svg and an .dxf file. I tried using those to create a 3d file but it seems that the two files aren't compatible with the modeling software.

Could you also tell me how you created the .svg and .dxf file?

Sono-Gomorrha, 2022-01-04:
What kind of software did you use? I had good results with FreeCAD when working with dxf files.

duckyb, 2022-01-30:
Closed for inactivity. Feel free to reopen/comment if needed.

Closed 2022-01-30.

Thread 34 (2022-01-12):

Feature request: hot swap socket support

dlip, 2022-01-12:
Would you be able to support hot swap sockets?

duckyb, 2022-01-12:
A problem with hot swap sockets is that the switches will be unstable unless you also have a plate to hold the switches. This has been discussed before in discord and some people have already tried to edit the PCB but I've yet to see a hotswap sweep

elisiano, 2022-01-16:
ooohhh the millmax support would be awesome, as it would be a lower profile than the hot swap socket!

duckyb, 2022-05-01:
Sweep v2.2 now supports millmax sockets.

Closed 2022-05-01.

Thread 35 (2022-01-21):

JLCPCB says "Panel by Customer" for Sweep 2.1

lzhang10, 2022-01-21:
I uploaded the Sweep 2.1 file to JLCPCB. When I choose Different Design to be 2 I can not pick "Single PCB" as Delivery Format. The other options are "Panel by Customer" and "Panel by JLCPCB".

Is it safe to set Different Design to be 1 so that I can use "Single PCB" as Delivery Format?

duckyb, 2022-01-21:
You can try and do that but they might stop your order and tell you "This is not a single design". Because the two PCBs don't have an electrical connection between them and they have different silkscreens etc.

I would suggest ordering a Sweep half-swept instead, if you want to be sure.

lzhang10, 2022-01-21:
Thanks for the explanation. I chose 1 design with Single PCB delivery and my order passed review.

Closed 2022-01-21.

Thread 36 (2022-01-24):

there is missing components.

partrita, 2022-01-24:
It just so obvious but

please add 1x TRS cable(3.5mm) and 2x TRS jack(PJ-320A)

thanks.

duckyb, 2022-01-25:
Thank you for reporting this issue, I have fixed it.
But take care; the cable you get **MUST be a TRRS** cable! (It should have 3 black rings on it)

partrita, 2022-01-25:
>

Oh, Thanks :)

Closed 2022-01-25.

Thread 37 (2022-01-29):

Top Plate Generation for Sweep High

ThePreviousOne, 2022-01-29:
How was the top plate for this created? I added a key to the design in KiCad but the cutouts I used for my design flie were too big so I pasted it over top of the Sweep's plate file and found that the holes don't even line up. This makes me wonder if the Sweep High plate even really fits, I'm sure it does but I don't know how else to explain this

davidphilipbarr, 2022-01-29:
The plate files are generated from the the main pcb with this footprint swapped for the switches

[SW_PG1350_cut.zip](https://github.com/davidphilipbarr/Sweep/files/7964082/SW_PG1350_cut.zip)

(and then the edge cuts modding)

The dxf and svg are exported from this. have look, let me know if you think what is there does not match up with the output from the plate files i have just uploaded.

good luck :)

ThePreviousOne, 2022-01-30:
Thank you so much, that worked, now I can finally finish my kb

Closed 2022-01-30.

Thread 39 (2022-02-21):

[Bling MX plate] Puck screws can't pass through the plate

duckyb, 2022-02-21:
The tenting puck screws cannot be removed easily while the plate is installed because the holes are too small.
Increasing the puck holes diameter fixes this issue.

This is considered a minor issue because the plate can still be removed by pulling out the switches.

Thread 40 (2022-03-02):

[Sweep High] Overlaps in edge cuts layer

John-Ingram, 2022-03-02:
Some there are some issues in the board outline (overlapping outline) for at least the Sweep-high board (although I expect that the issue affects the other boards also).

This issue can be demonstrated by trying to export the board in the IDFv3 format. If you open the generated.emn file in a text editor, you'll notice that there are only a few lines that start with zero. These lines are the coordinates for the board outline, and there should be more of them.

The fix for this issue is to go through the board outlines and check every segment of the board outline to make sure there are no errors.
I will do this for the Sweep-high board sometime soon, but I figured I'd let everyone else know until then.

JiaGengChang, 2022-03-16:
I have tried to build a sweep high, and a lot of the keys on the right side are not working. Is that related to this issue?

duckyb, 2022-03-17:
@JiaGengChang No

duckyb, 2022-04-24:
Fixed in https://github.com/davidphilipbarr/Sweep/commit/972bf728dd9374cb81e3659c3c51c807ad7520d0 but some more fixes are needed before I can merge / update the gerbers

duckyb, 2022-04-25:
Merged https://github.com/davidphilipbarr/Sweep/commit/f87ba64e6f716add1bc7cf43377e1d57bf9c240c

Closed 2022-04-25.

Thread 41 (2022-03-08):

Support for BlackPill (STM32F4X1)

matru, 2022-03-08:
Will this be available in the future, it is a bit wider and lengthier compared to the ProMicro/Elite-C.

STM32F4X1, it goes by BlackPill too, is a much more powerful MCU, USB-C, open-source (https://github.com/WeActTC/MiniSTM32F4x1), it is officially manufactured by WeAct at this moment, and it is also priced very low at $7 + shipping, it was even lower I believe. Of course it is officially QMK supported.

Would be awesome to see this one more widespread.

duckyb, 2022-03-08:
> "You can get usb c promicros now which was the big sell of the black pill originally, we don't need the additional power or memory." - @davidphilipbarr

It would be nice to support everything but that would require having a large amount of different sweep versions. After supporting the blackpill for choc people would ask to also support it for mx or vice versa. Same goes for all other sweep versions.

So it won't be done, but you are welcome to fork the repository and create your own version with BlackPill support ✌🏻

Closed 2022-03-08.

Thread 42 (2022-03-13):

[Sweep v2] Some switches occasionally stop working or get stuck

plattfot, 2022-03-13:
This is probably not the right place to ask and feel free to close if it is not.

I assembly one Ferris Sweep v2.1 after ordering 5 PCBs from JLCPCB (thank you for the walk through on that).

Everything was straight forward, I only had one issue with one of the PCB's hole for the micro controller. Two of the holes was too small so the micro controller didn't fit. But the second board I tried worked out perfectly.

The main issue I have is after a while a key on my left hand will stop working. Mainly this will be `c`, but I have seen `w` and `t` as well. The strange part is that if I press any other key on the left hand the dead key will be pressed and stay pressed until I disconnect the keyboard.

First I thought it might be because of bad soldering. But I've re-solder all switches, pins for the trrs and micro controller.

I have checked with a multimeter for shorts and if the switches work. Everything looks good. For example if I remove the micro controller, hook up the multimeter to pin 23 (GND) and pin 7 (Switch 13 aka `c`). Then press `c`, the multimeter register the press. And no other key triggers it.

I have swapped out the Elite-C micro controller for a Pro micro I had in another Keyboard. Same issue.

I don't see any damage on the PCB.

I've tried `QMK Firmware 0.15.23` and `0.15.12`. But I doubt it's a bug in qmk.

Any idea what can cause this?

edit: Having `backspace` and `enter` on the same key but different layers turns out to be a really bad idea. Was suppose to press `ctrl`+`backspace` but instead it became `ctrl`+`enter`  :man_facepalming:.

duckyb, 2022-03-13:
Check this, and skip the part about diodes:

https://docs.splitkb.com/hc/en-us/articles/360010552339-One-or-more-keys-don-t-work

plattfot, 2022-03-13:
Thanks for the link.

I did do a second pass today and notice some flux residue on the front of the board. I had some issues with soldering one of the legs for the choc switches so I had used some extra flux I had lying around to solder them properly. That looks to be my mistake though. As after I had desoldered one of the switches, the bottom of it was covered in flux residue. So I just desoldered all the switches, cleaned them, moved everything except the low profile sockets to a new board. In case there are other issues with that particular pcb.

And now everything seems to be working. :crossed_fingers:

My guess is the flux that pored down the legs of the switches, caused a short. Which also explain why it worked sometime and why different keys stopped working.

Lesson learned:
- Don't use extra flux when soldering through hole.
- Use a better tip when soldering. I changed to another tip and that made it much easier to solder those legs.

And I'm glad I socketed the micro controllers. Made it much easier to debug and I didn't have to desolder one of them when changing board.

And thank you for making the pcb open source! Was pretty straight forward to just open kicad and see where the traces are on the board.

Now I'm going to enjoy my ferris sweep!

duckyb, 2022-03-14:
Good to hear you were able to fix it, have fun!

Closed 2022-03-13.

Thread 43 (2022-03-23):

Which is the behaviour of the on/off switch?

leiserfg, 2022-03-23:
I got a preassembled sweep with nice!nanos but it seems like the switches don't turn it off, is that the intended behaviour or is it incorrectly mounted?

davidphilipbarr, 2022-03-24:
sounds like something is wrong there, do you have some photos of the
switch/battery connection?

On Wed, 23 Mar 2022 at 19:34, Leiser Fernández Gallo <
***@***.***> wrote:

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

leiserfg, 2022-03-24:
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

leiserfg, 2022-03-24:
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

leiserfg, 2022-03-24:
I took the picture with the switch on and off but I can type with it no matter what

duckyb, 2022-03-24:
@leiserfg How can the switch do anything if the battery is directly connected to the nice!nano?
In order for it to work, the battery must be connected to the sweep PCB.

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

duckyb, 2022-03-24:
In case you don't have the tools to fix it, I recommend using these settings in your cradio.conf

```py
# enable deep sleep support
CONFIG_ZMK_SLEEP=y

# the keyboard disconnects from bluetooth.
# uses very little power, but it may take
# a few seconds to reconnect after waking.
# 1.800.000 ms = 30 minutes
CONFIG_ZMK_IDLE_SLEEP_TIMEOUT=1800000
```
(adjust timeout value according to your preference)

leiserfg, 2022-03-24:
Thanks a lot, I supposed it was not well wired but didn't know the correct way to do it, I'll recompile the firmware that way and try to rewire it once I get a good iron.

Closed 2022-03-24.

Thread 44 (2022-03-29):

[Bling Mx] Artifact left on bottom plate

zachatttack, 2022-03-29:
JLCPCB informed me that this artifact was left on the gerber file, and wanted to know if it should be deleted before proceeding.

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

duckyb, 2022-03-29:
@zachatttack yeah, it was used for alignment when designing the puck cutout. I will remove it and update the gerber. Thanks for reporting.

duckyb, 2022-03-29:
Fixed in [039183f](https://github.com/davidphilipbarr/Sweep/commit/039183f5cfd70f759bea55cf093227618b1d3112)

Closed 2022-03-29.

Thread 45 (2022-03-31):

Sweep2 vs Sweep Bling MX

p0da, 2022-03-31:
Just looking for a quick clarification on which type I should build as while the Sweep2 is currently recommended, the Sweep Bling MX seems to be just an overall better version of the Sweep2. Are there any drawbacks to the Bling MX that the 2 doesn't have aside from what is listed on the comparison chart? Thanks for the help, kinda new to the space.

duckyb, 2022-03-31:
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

The main difference is that one is for choc switches, the other is for MX switches.

p0da, 2022-04-01:
That clears up my question perfectly, thanks for the help. And that chart is really useful might want to put it on the README.

Closed 2022-04-01.

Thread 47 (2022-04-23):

Reset button for the compact low version

riveraletelier, 2022-04-23:
First, thanks for putting all of this together.

There is a small issue with the description. It recommends the Omron B3U-1000P(M) for the reset button. It works well, expect for the compact low version that is designed for a through hole button. It would seem that the Apem MJTP1243 button would work, but I haven't tried it yet. Here is a link with to the datasheet in Digikey:
https://media.digikey.com/pdf/Data%20Sheets/APEM%20Components%20PDFs/MJTP%20Series-6MM.pdf

duckyb, 2022-04-23:
Thanks for reporting this issue. I will replace the footprint on the compact low to use the `Omron B3U-1000P(M)` component instead.

riveraletelier, 2022-04-28:
That would be great, thanks!

duckyb, 2022-05-19:
Fixed and merged

Closed 2022-05-19.

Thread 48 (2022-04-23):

Sweep High Plated Slot Width

ballin2much, 2022-04-23:
Trying to purchase sweep high from JLBPC and they are saying the following:
"the minimum width of plated slot need to be 0.5mm or more, could we enlarge the width of 0.3mm and 0.4mm slots to 0.5mm?"

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

Very unfamiliar with PCB design so I'm unsure if this is an issue with the gerber file, if I did something wrong, or if I just need to tell them that it is fine to enlarge.

duckyb, 2022-04-24:
@ballin2much Reply:

```
Yes, you can enlarge the slots to 0.5mm.
Thanks.
```

This is the second time they complain, we should change the footprint.

ballin2much, 2022-04-24:
Thanks for the quick reply. Appreciate all the documentation/tutorials.

duckyb, 2022-04-24:
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

Updated the silk screen and enlarged the slots

duckyb, 2022-04-25:
This issue is now fixed: https://github.com/davidphilipbarr/Sweep/commit/f87ba64e6f716add1bc7cf43377e1d57bf9c240c
The gerber is updated to the new version.

Closed 2022-04-24.

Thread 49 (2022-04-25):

[Sweep High] Unable to view gerber on JLC quote page

duckyb, 2022-04-25:
Known issue. It has been reported to JLC.
You can still order the board from them and it should work fine.

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

Closed 2022-05-30.

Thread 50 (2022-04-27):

PJ-320A alternative wiring

sommerper, 2022-04-27:
First of all many thinks for proving the files for this project!

It's my first time venturing into making my own keyboard.

Unfortunately I find it impossible to get a hold of the PJ-320A connectors so I was thinking of just using an alternative connector.

I'm just not sure the TRRS connection is wired. Is it something like this: https://imgur.com/a/S2gD4Yt
Again. Thanks for the awesome project!

sommerper, 2022-04-27:
Thank you for the links. I have ordered some from China now.
And thanks for confirming my assumption!

Closed 2022-04-27.

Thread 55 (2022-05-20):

[Sweep v2] Peripheral side not sending inputs

rodrigocam, 2022-05-20:
Hey, I build a sweep keyboard v2 but it only works the half connected to the USB. I have a TRRS cable but it didn't work. I have tested the continuity of the holes of the TRRS jack in the PCB and I found a strange behavior, the two holes in the picture below give continuity, is it right?

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

davidphilipbarr, 2022-05-20:
They should both be gnd, so that is normal. Do you have some pics of the
top and bottom of your board?

On Fri, 20 May 2022, 20:49 Rodrigo Oliveira, ***@***.***>
wrote:

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

rodrigocam, 2022-05-20:
Yes, the one assembled and the other factory new:

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

rodrigocam, 2022-05-20:
1. Test that all pins on the VCC net are connected ✅
2. Test that all pins on the switch 18 net are connected ✅

duckyb, 2022-05-20:
> 1. Test that all pins on the VCC net are connected ✅
> 2. Test that all pins on the switch 18 net are connected ✅

Then it shouldn't be a hardware issue 🤔

rodrigocam, 2022-05-21:
Is it possible I'm flashing the wrong firmware? I'm using this one https://config.qmk.fm/#/ferris/sweep/LAYOUT_split_3x5_2

duckyb, 2022-05-21:
@rodrigocam try to flash eeprom right/left on your respective micro controllers
`QMK Toolbox > Tools > EEPROM > Set L/R`

daskygit, 2022-05-21:
You're likely going to want to compile firmware with a option enabled.

Try add `#define SPLIT_USB_DETECT` to your config.h and flashing both sides.

This changes the USB detection so it doesn't use VBUS sensing which can be a problem with some promicros.

rsteube, 2022-05-21:
Second on the [SPLIT_USB_DETECT](https://github.com/rsteube/qmk-keymap/blob/master/ferris-rgaertner/config.h#L8). Coincidentally also had the issue today where it seems the promicro always tried to be master.
I think sth. is up with  [J1](https://docs.splitkb.com/hc/en-us/articles/360010588860-Only-one-half-of-my-keyboard-works-at-a-time-but-not-when-they-are-both-connected) which apparently is bridged although the pads are clean.
Adding the config fixed it.

rodrigocam, 2022-05-23:
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

This worked like a charm, thanks! 👍

mladedav, 2023-04-11:
I've just run into the same issue. Is there a downside to using this option or can I try and add this option to the qmk firmware?

cgahr, 2024-02-13:
I have the same issue. However, for me, `#define SPLIT_USB_DETECT` does not solve the problem.
VCC net and switch 18 net are fine for me too.

Any help would be appreciated!

duckyb, 2024-02-13:
> I have the same issue. However, for me, `#define SPLIT_USB_DETECT` does not solve the problem. VCC net and switch 18 net are fine for me too.
>
> Any help would be appreciated!

1. Make sure you are using a TRRS cable and not a TRS.
2. Connect the cable and test net 18 with the cable connected. Also test that parts that should be on different nets are not connected (shorts).

cgahr, 2024-02-14:
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

1. I'm using a TRRS cable
2. VCC and net 18 both look good, with cable connected
3. I couldn't find any short
4. each half individually is working fine

I compile with the following command
```
qmk compile -kb ferris/sweep -km ryoku -e MAKECMDGOALS=uf2-split-left -e TARGET=sweep_ryoku_left
qmk compile -kb ferris/sweep -km ryoku -e MAKECMDGOALS=uf2-split-right -e TARGET=sweep_ryoku_right
```
and
```
# rules.mk
CONVERT_TO=elite_pi
SPLIT_KEYBOARD = yes
CONSOLE_ENABLE = yes
```
```
\\ config.h
#define SPLIT_USB_DETECT
#define SERIAL_DEBUG
```

When I run `qmk console` and conntect my keyboard, I get:
```
DPB:Ferris sweep:1: SPLIT: receiving handshake failed
DPB:Ferris sweep:1: SPLIT: receiving handshake failed
DPB:Ferris sweep:1: SPLIT: receiving handshake failed
DPB:Ferris sweep:1: Failed to execute slave_matrix
DPB:Ferris sweep:1: Target disconnected, throttling connection attempts
DPB:Ferris sweep:1: SPLIT: receiving handshake fail
```

duckyb, 2024-02-15:
@cgahr I would recommend taking this to [QMK's discord chat](https://discord.gg/Uq7gcHh) as I don't know how to help you and not many people will be looking at this page.

cgahr, 2024-02-15:
Thank you anyways :)

Closed 2022-05-23.

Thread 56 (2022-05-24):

Sweep Compact Low  (additional keys)

zaddok, 2022-05-24:
This looks like an amazing project, thanks so much for this work!

It looks like the “Sweep Compact Low - The only version that supports Choc minis.” Would be my ideal keyboard, but with an couple of extra custom keys. I type with some other languages that at have some additional needs.

Maybe three keys added on each end (6 keys), or maybe two keys added for each thumb (4 keys)

I was thinking of trying to learn how to to do that, but I wanted to check if anyone had done anything like this before.

duckyb, 2022-05-24:
If you want to **not** use diodes / switch matrix you can only have 1 key per switch pin. This puts a limit of 17 keys per side with a pro-micro. You can get extra keys only if you use a switch matrix with diodes, or if you use an elite-c and make use of the extra pins.

davidphilipbarr, 2022-05-24:
The sweeeeep uses the extra pins from the elite-c for leds and a screen:

https://github.com/sadekbaroudi/sweeeeep

the cantor uses a black pill to get the extra pins:

https://github.com/diepala/cantor

They might be of interest?

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

Closed 2022-05-25.

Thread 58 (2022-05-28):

[Sweep v2] Too many slots / Extra drill time fee

muk343, 2022-05-28:
When I upload the sweep2.2 related gerber file to jlc with the recommended config, they complained about having too many small slots and asked me to pay extra. Is it an issue which many people have faced?

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

duckyb, 2022-05-28:
This is not common from my experience. You got unlucky with the engineer that checked it, maybe they were in a bad mood.

Try to order on a different day, or try PCBway instead

Closed 2022-05-30.

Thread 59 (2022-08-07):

Mill Max for Sweep Bling LP?

18goldr, 2022-08-07:
Hi, the table says you can use kailh hotswap switches for the Bling LP, but it doesn't specify if you can use mill max hot swap for the micro controller. Can you?
Thanks!

duckyb, 2022-08-07:
Millmax headers for micro controllers are supported by all versions

Closed 2022-08-07.

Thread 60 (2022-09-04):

feature request: support hot swap sockets so switches can be changed

jordanst3wart, 2022-09-04:
I think there is a use case for hot swap sockets. I think it is nice have switches that can be recycled, and it's easier to replace and try other switches

support sockets such as these:
https://keyhive.xyz/shop/kailh-sockets

duckyb, 2022-09-04:
They are already supported by `Sweep Bling MX` and `Sweep Bling LP`.

Closed 2022-09-04.

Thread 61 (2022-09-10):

Ferris sweep on nRFMicro

conceptroot, 2022-09-10:
Hi guys.
Is it possible to use nRFMicro instead of Nice!Nano in Ferris Sweep?
It is almost impossible to get Nice!Nano in my country.

If ferris sweep runs on nRFMicro, it would be great to indicate it in documentation.

GerardoNevarez, 2022-09-10:
there's no reason why it should not work... just need to make sure the headers are slightly more open, in case the eByte module bumps into them.

See the module on top, and how close the headers will be with the nrfmicro upside down.  just open them a bit to the sides.  [nrfmicro with shield removed ](https://user-images.githubusercontent.com/852547/136052828-7e8c5e5a-bf60-4805-b5f9-ffaaf6725221.jpg)

duckyb, 2022-09-10:
| header | pcb clearance |
| --- | --- |
| 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 | 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 |

conceptroot, 2022-09-11:
Thanks for replies guys.
It should work I guess. I asked a guy ufan (https://github.com/ufan/sweepro-ce), and he has regular sweep on nRFMicro.
Here is a picture of regular sweep on nRFMicro:
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

I ordered all PCBs in JLCPCB and in couple of month I'm gonna try this build (nRFMicro on Sweep LP).
I'll let you know if it works.

duckyb, 2022-09-11:
@conceptroot good luck! 🍀

Closed 2022-09-11.

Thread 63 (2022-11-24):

Feature request: Battery JST connector

shrekale, 2022-11-24:
We need JST connector for battery connection instead of soldering wires on there.

davidphilipbarr, 2022-11-25:
Need is a very strong word :)

There is a version where the jst connector sits over the trrs, as you would
never use both together.

I'll see if i can dig it out

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

shrekale, 2022-11-25:
I am actually working on replacing TRRS with that JST, With NiceNanos we don't use it anyway, those MCs can't communicate through TRRS. If there's a branch that has that, please let me know, or I will do some KiCAD work & get it done for myself.

shrekale, 2022-11-25:
If you can't find, I will push my version named properly in one folder, others will use it then.

davidphilipbarr, 2022-11-25:
https://github.com/davidphilipbarr/testing-boards/tree/main/Sweep%20v2.2-jst

This is the version I have, but unless someone else tests it it will remain
in limbo.

There is also an older sweep with the trrs removed.

https://github.com/davidphilipbarr/testing-boards/tree/main/Sweepv2.1-nt

Feel free to add yours too :)

cheers

David

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

shrekale, 2022-11-25:
Nice. Thanks! Let me see this & if mine's better, I will check it in. I can see why it's not just one version of the PCB & there are subfolders, people might not want it wirelessly, they might need TRRS.

Closed 2022-11-25.

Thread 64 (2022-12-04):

Question: Why are the switch holes and solder pads on the Sweep Bling MX rotated upside-down

smoky19x, 2022-12-04:
Hello,

i wonder why the switch holes and solder pads on the Sweep Bling MX are rotated upside-down. What is the reason for this? The space on the PCB should be enough to align it the "normal" way around, or?

duckyb, 2022-12-04:
It's better to have south facing switches when LEDs are not involved. North facing switches can cause interference with Cherry profile keycaps. (The keycap hits the housing of the switch on the downstroke)

smoky19x, 2022-12-04:
OK, thanks for the explanation.

Closed 2022-12-04.

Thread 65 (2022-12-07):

Dimensions for Bling MX switch plate/back plate unclear

astralbat, 2022-12-07:
Hello,
When I was ordering the switch plates and back plates, I was not sure if these were the same dimensions mentioned for the PCB. I assumed they were, but the uploaded gerber for the switchplate has a different dimension in the filename.

In the end, when ordering, I assumed they were all the same dimension as the PCB and that the filename has a typo.

This is particularly a problem with the swithplate as JLCPCB did not autodetect them or render the result.

Thanks.

duckyb, 2022-12-07:
The files have been ordered successfully before, so I don't think you need to worry about it.
I will check if the dimensions in the filename are correct or not, all I can say for now is that they are auto-generated by a plugin.

duckyb, 2022-12-07:
Also, the dimensions on the quote page are only needed to calculate the cost of the order. Their machines will reference what's in the file to make the PCB.

astralbat, 2022-12-07:
I see, it was my assumption the dimensions would scale the board. I think it would be good to clarify a little more on the readme. Thanks.

Closed 2023-01-31.

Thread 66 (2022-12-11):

Add switch plate and bottom plate for the Sweep High M

isacben, 2022-12-11:
Hi,

It would be nice to have switch and bottom plates for the Sweep High M version.

The switch plate would be specially important because the Sweep High M version requires Kailh switches with no alignment pins, which makes it difficult to solder them aligned.

Thanks!

duckyb, 2022-12-11:
I think the bling mx plate might be compatible with it

isacben, 2022-12-11:
Thanks, Duccio,

I was wondering about that, and I printed both PCBs on paper. It looks aligned, but I cannot confirm that it works. Would have to order the PCBs.

duckyb, 2022-12-12:
The switch plate will work. The only problem is that it will cover the reset button location.
The bottom plate PCB will not work with it because the main PCB is missing the holes for mounting hardware.

If someone wants to add those holes in the correct location feel free to submit a pull request.

isacben, 2022-12-12:
Thanks!

Closed 2022-12-19.

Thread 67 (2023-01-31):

Standoff/Spacer Holes for Sweep Bling MX/LP are too tight

hmngwy, 2023-01-31:
I'm using M2 hex spacers and they have an outer diameter of 3.0mm. M2 knurled spacers have an outer diameter of 3.1mm. The hole looks like it measures 3.2mm, however due to fab tolerances they come out around 3.1-3.2mm, they are a tad bit too tight, with some pressure they will go in, but I think 0.1mm (max) increase in diameter would fix this issue.

duckyb, 2023-01-31:
The diameter was chosen for this type of spacer, which measures 3.00mm in diameter. Are you not using this type of spacer?

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

duckyb, 2023-01-31:
These are the tolerances according to [JLC's capabilities documentation](https://jlcpcb.com/capabilities/pcb-capabilities)

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

Since the drill hole is set to `3.2mm` it can be manufactured from `3.12mm` to `3.33mm`, so it should always fit the `3.00mm` spacer.

hmngwy, 2023-01-31:
I see, I did suspect I am getting the low end of that manufacturing tolerance, my PCBs read 3.1mm at that hole using a caliper.

I do have those knurled standoffs, as well as hex ones, however, they have manufacturing a tolerance of +/-1mm, and my standoff's diameter 3.1mm (splitkb.com also lists theirs as 3.1mm and not 3.0mm).

I think for wider compatibility with various sources of these spacers, and to accommodate the drill hole tolerances, it may still be worth adding .1mm to increase the chances of compatibility.

duckyb, 2023-02-01:
Fixed in 31fb1d708d5e074c8c72d372f89e7fc1b5d0feb9

matru, 2023-02-02:
@duckyb @hmngwy

I know that on splitkb the diamter is 3.1mm on the knurled cylindrical ones, but every top search I did with standoff/spacer keyword on aliexpress, was 3.2mm diameter for knurled cylindrical ones, 3.3mm max diagonal for hex. Actually could not find something else then these dimensions for an m2.

https://www.aliexpress.com/item/1005001478301407.html
https://www.aliexpress.com/item/1005003106030065.html
https://www.aliexpress.com/item/1005001479466801.html
https://www.aliexpress.com/item/1005001478301407.html
https://www.aliexpress.com/item/1005001479466801.html
https://www.aliexpress.com/item/32841023756.html
https://www.aliexpress.com/item/1005002467410552.html
https://www.aliexpress.com/item/32863484622.html

duckyb, 2023-02-02:
Thank you for your effort @matru

Now the holes have been changed to 3.35mm which should be enough for the brass spacer. The hex spacer is out of scope for this issue.

matru, 2023-02-03:
@duckyb thanks! What hole diameter does the other variants use, especially the Sweep v2+?

duckyb, 2023-02-03:
> @duckyb thanks! What hole diameter does the other variants use, especially the Sweep v2+?

The Sweep v2 does not have holes for standoffs

matru, 2023-02-04:
@duckyb oh, right. This is not something intentional I assume, there has been simply no development on it?

duckyb, 2023-02-04:
@matru yes. Since it doesn't have a plate case the standoffs are not needed.

Closed 2023-02-01.

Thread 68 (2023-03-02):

Where to source batteries?

JezThePhilo, 2023-03-02:
Any info on what kind of batteries should we use? The ones listed in desc of the YT video are not on Ebay anymore :/

zaddok, 2023-03-02:
The numbers for thus type of battery are simply the height and width and length of the battery. If you choose a different number, inside the exact same type of battery, it’ll just be a different size and hold more or less charge depending on the size you selected.

duckyb, 2023-03-03:
These work fine in my experience https://aliexpress.com/item/4001104720491.html

Closed 2023-03-08.

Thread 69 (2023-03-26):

[Custom Sweep v2]: Keys not registering

Sheape, 2023-03-26:
Believe it or not, it's been 11 months since I ordered all the parts and everything but I still haven't fixed my keyboard since then. Before I would solder the key switches, connector, and pro micros, I want to test if every keys work as intended (based from my layout) but none of the keys register. However, I tried to move around a thin wire around the pro micro and it does register the keys which means the problem isn't from my keyboard layout/firmware. Im not really sure if it's my pcb that's causing the problem, when I ordered it from JLC, they checked it and everything is fine. Please if anyone can verify if my pcb is correct, I will appreciate it.

[ferris-sweep-edge-cut-master.zip](https://github.com/davidphilipbarr/Sweep/files/11070724/ferris-sweep-edge-cut-master.zip)

duckyb, 2023-03-26:
Is it a Sweep Half Swept or Sweep Bling MX?

davidphilipbarr, 2023-03-26:
the kicad files look ok, so pix plz!

On Sun, 26 Mar 2023 at 04:49, Paul Gerald Pare ***@***.***>
wrote:

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

Riccardo-merli94, 2023-03-29:
I’m currently having the same issue using the half swept.
I’m not an expert but my understanding is that one pin of the switches should always go to ground, in my pcb all the switches had a ground connection except for one and it looks like that one brings GND to the microcontroller as well.
my first thought was that was a mistake on the design and I connected the ground with a wire. It did work, when connected via usb, but I’m having issues if I connect the battery. I checked for shorts or wrong connections but I couldn’t find any. The only charge I made was to the outline to change the cut.

duckyb, 2023-03-29:
@Riccardo-merli94 please check the schematic pdf available in the repository and make sure your pcb matches the schematic. The Sweep is a very well tested design so I think we can rule out any issue with the PCB design.

Riccardo-merli94, 2023-03-30:
That’s exactly what I thought, I’ll do some more digging. In case I can’t figure it out, would you be able to give me a little help?

duckyb, 2023-03-30:
> @duckyb That’s exactly what I thought, I’ll do some more digging. In case I can’t figure it out, would you be able to give me a little help?

I can't promise anything, but we'll see

Sheape, 2023-03-30:
> the kicad files look ok, so pix plz!
> […](#)
> On Sun, 26 Mar 2023 at 04:49, Paul Gerald Pare ***@***.***> wrote: Believe it or not, it's been 11 months since I ordered all the parts and everything but I still haven't fixed my keyboard since then. Before I would solder the key switches, connector, and pro micros, I want to test if every keys work as intended (based from my layout) but none of the keys register. However, I tried to move around a thin wire around the pro micro and it does register the keys which means the problem isn't from my keyboard layout/firmware. Im not really sure if it's my pcb that's causing the problem, when I ordered it from JLC, they checked it and everything is fine. Please if anyone can verify if my pcb is correct, I will appreciate it. ferris-sweep-edge-cut-master.zip <https://github.com/davidphilipbarr/Sweep/files/11070724/ferris-sweep-edge-cut-master.zip> — Reply to this email directly, view it on GitHub <#69>, or unsubscribe <https://github.com/notifications/unsubscribe-auth/AAAW5MWHRFWMOG65ORPENVTW564DXANCNFSM6AAAAAAWH5QHD4> . You are receiving this because you are subscribed to this thread.Message ID: ***@***.***>

damn, thanks for checking it. I'll provide some images of my setup and my layout (just in case that is the problem) later on. Im not really sure what's wrong tbh

Riccardo-merli94, 2023-03-31:
> > @duckyb That’s exactly what I thought, I’ll do some more digging. In case I can’t figure it out, would you be able to give me a little help?
>
> I can't promise anything, but we'll see

It turned out it was my fault 🤦🏻‍♂️, when I edited the outline for the cutout I accidentally move the edge too close to the power switch and this caused to isolate the right side with the left side. I believe that I can fix it by jumping the two sides with a cable for now, but I’m not 100% sure 😅.

Closed 2023-04-09.

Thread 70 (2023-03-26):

How to build a gerber (wanted to add custom silkscreen) for KiCad 7?

vladimirlucifer, 2023-03-26:
Why hello! I wanted to get a PCB of the Sweep v2.2 on jlcpcb and the provided gerber file works just fine (as in, it displays just fine)! However, when I try to add a custom Silkscreen and try to plot it (on KiCad 7) with the website's recommended setting, it does not work (as in, it does not display). What are the settings used to get the provided gerber, so that I can also be sure it is 100% compatible? Many thanks. I also think this may be related to some mising libraries, but I would not know how to properly check and fix that, as I am an absolute noob when it comes to KiCad and other CAD software.

duckyb, 2023-03-26:
The gerber preview viewer from JLC is super unreliable, don't stress about it. A JLC engineer will have to check the file regardless and they will email you if there are any apparent problems.

vladimirlucifer, 2023-03-26:
Thanks! I ended up committing the sin of just substituting the silkscreen layers, and letting everything else be as provided. But with those news, I feel safer and more confident, thank you!

Closed 2023-03-26.

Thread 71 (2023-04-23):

Sweep Half Swept - both sides show 'place MCU with components facing down'

anahodil, 2023-04-23:
As it says in the title, both sides of the Sweep Half Swept say to place the MCU with components facing down. I was under the impression that once side (from what I have seen in videos, the right side) should have the components facing up. Does anyone know if what the board says is correct, and that both sides should be components down?

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

duckyb, 2023-04-23:
Yes, follow the instructions on the PCB.
The version that had one facing up has been archived. On all current sweep versions both controllers are face down.

Closed 2023-04-23.

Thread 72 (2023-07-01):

Is this keyboard supposed to work plugged in to either side?

jonathanhirz, 2023-07-01:
Hi, sorry for the newbie question. When I have the usb plugged into the right side of this keyboard (pro micro boards), I get key presses from both sides. If I plug into the left side, I only get keypresses from the left side. Is this supposed to work this way, or should it be able to be plugged in either way? I did set handedness, and when both sides are working I see the correct keys coming through.

LED colors are odd two, left always lights up red, right is green, no matter which one is plugged into usb.

Thanks.

duckyb, 2023-07-01:
With handedness setup correctly you should be able to plug in on either side.

jonathanhirz, 2023-07-01:
Alright thanks, I must have something wrong somewhere then.

Closed 2023-07-01.

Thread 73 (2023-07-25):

any interest in a diodes sweep?

idank, 2023-07-25:
Hello,

I took the sweep pcb and added diodes to it so the SDA/SCL pins can be freed for things like a trackball or OLED screen. I also made it hotswappable while I was at it. Apart from that, it's identical to the OG sweep.

Any interest in adding this variant to this repo?

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

duckyb, 2023-07-25:
I don't think it's a good idea to add it to the repo because using diodes is not in the spirit of the sweep. Also since you are using a different pin-out of the micro controller this would be the only sweep that is not compatible in firmware.

I also made something similar to this but it has it's own repo: https://github.com/duckyb/urchin

idank, 2023-07-25:
It doesn't have to use the same firmware, it could sit under `ferris/sweepdiode` or whatever. But the rest makes sense so I'll keep this separate, thanks!

duckyb, 2023-07-25:
I know it doesn't _have_ to use the same firmware, but all other sweeps do. So this one would be the odd one out.

Closed 2023-07-25.

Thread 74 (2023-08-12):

J1 Jumper Issue

jdc75, 2023-08-12:
Hi,

basically I am facing the same issue addressed in #55 but the measurements given did not resolve it for me. I tested for continuity on the VCC net as well as switch 18 net as indicated by @duckyb which were fine. I added both `#define SPLIT_USB_DETECT` as well as `#define SPLIT_USB_TIMEOUT 2500` to my config and flashed both sides. They are working when only one of them is connected to the computer.

While testing for functionality I noticed an unexpected behavior - at least for me. When one side e.g. right hand is connected to the computer and a TRRS cable is conneted to it which is **not** plugged in to the other hand the right hand stops working. Is this how it should be?

I stumbled across an [article](https://docs.splitkb.com/hc/en-us/articles/360010588860-Only-one-half-of-my-keyboard-works-at-a-time-but-not-when-they-are-both-connected) which is stating that this could be related to J1 Jumper pad found on some pro micro mcs - same goes for mine. The solution should be desoldering the presoldered J1 Jumper on the intended passive side. Has anyone here experience on this?

duckyb, 2023-08-12:
Which micro controller are you using? Are you sure the cable is TRRS and not TRS? Are you hot-plugging the TRRS cable?

jdc75, 2023-08-12:
Thanks for the quick answer.

I am using the [diymore Pro Micro](https://www.amazon.de/gp/product/B0BKGSVX2X/ref=ox_sc_act_title_1?smid=A2OYQMAUQB5NOO&psc=1). For the cable I am using [this one](https://www.amazon.de/dp/B01I0SI1SG?ref=ppx_yo2ov_dt_b_product_details&th=1). I feel a little bit ashamed to admit, that I have bought the wrong cable as it seems (product page states TRS somewhere) even though I read the information on the bill of material. I ordered a new cable which is TRRS for sure. I will update you once it arrives.

I generally avoid hot-plugging to not damage my mcs.

duckyb, 2023-08-13:
@jdc75 nothing to be ashamed, it's a common mistake. You can tell the type of cable by counting the metal parts at the end. Your cable has TIP RING SLEEVE, while a TRRS cable would have TIP RING RING SLEEVE.

I'll consider this resolved for now, you can reopen it later if necessary.

Closed 2023-08-13.

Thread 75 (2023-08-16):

Sweep v2.2 Schematic Wrong?

Allstreamer, 2023-08-16:
I've been looking at the Sweep v2.2 Schematic and PCB design a bit and noticed that it seems like the connection for Switch 15 and Switch 1 are mixed up in the Schematic. The Schematic Shows Switch 1 being connected to D7
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
But on the board it's actually connected to E6
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

I've potentially spotted more such errors but i'm not sure yet.

duckyb, 2023-08-16:
Repeating what I answered on Discord:
> I am aware of this issue. This is a problem affecting only the schematic file, the actual PCB is fine and would be manufactured correctly. This issue happened because over time, changes had been made to the PCB without keeping the schematic updated. You can temporarily refer to the Sweep Bling LP's schematic file which is more recent and up to date.

To fix this issue the V2 schematic should be updated to mirror the bling LP schematic.

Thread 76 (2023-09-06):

Is there any top plate for the sweep LP?

jittapont, 2023-09-06:
Hi,
I want to know if there is any top plate for the choc switches to sit in for sweep LP?
Thanks a lot

duckyb, 2023-09-06:
There is not

DusanLesan, 2025-02-28:
@duckyb Can this be reopened as feature request? I have some issues with lose hotswaps on my Sweep Bling LP so I would like to get a gerber file to have FR4 top plates created

Closed 2023-09-07.

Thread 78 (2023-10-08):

Short at TRRS jack

cgahr, 2023-10-08:
In my PCB, at the TRRS jack, there is a short between the following two connectors:
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

Is this correct?

EDIT:
also, looking at the PCB schematics in more detail, it looks like the `S gnd` (the bottom, single one) is connected to nothing?

duckyb, 2023-10-08:
Yes this is normal.

Closed 2023-10-08.

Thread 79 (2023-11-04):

Question: Switch compatability

SolninjaA, 2023-11-04:
Hi, I just have a quick question regarding the switch compatibility on the Ferris Sweep boards. I'm looking at the compatibility table, but I don't know if I fully understand it.

Am I correct in assuming that the Sweep2.x, Sweep Bling LP, Sweep High and Sweep Half Swept only support Choc v1 switches (except for the Sweep High, which supports multiple)?

Furthermore, am I correct in assuming the Sweep Bling MX, Sweep High and Sweep High M are the only models which support MX style switches (e.g. Gazzew Boba LT, Gateron Milky Yellows)?

Also, I had a look at an interesting switch but I'm not sure if it's compatible with any of the models. The switch I am talking about is: https://www.lofree.co/products/lofree-flow-the-smoothest-mechanical-keyboard?variant=44226590474459

If anyone could help me with these questions, I would greatly appreciate it.
Thanks.

duckyb, 2023-11-05:
All your assumptions are correct, I don't know if that switch is compatible.

SolninjaA, 2023-11-06:
Thanks for replying! I'm surprised that my assumptions are correct :)

I only want and need MX-style switches. Since this is the case, do you think the Ferris Sweep Bling MX would be the best? It looks to me like it's the only model with hotswap compatibility.

Also, regarding the "⚠" symbol on the compatibility table for the Sweep Bling MX, is that just saying it won't work with Alps switches but works perfectly with MX switches and that it requires hotswap sockets to be installed to work?

Thanks.

duckyb, 2023-11-06:
Yes I would recommend the bling mx.
Yes that's what the warning symbol is for.

SolninjaA, 2023-11-13:
Great, thanks so much!

Closed 2023-11-13.

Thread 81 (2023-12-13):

Sweep High M variant has silkscreen on the microcontroller contacts preventing soldering

eallenwright, 2023-12-13:
Sweep High M variant has silkscreen on the microcontroller contacts preventing soldering. I believe the intent is to solder the microcontroller on the right half face down, but still on the top of the board. This is currently not possible due to the silkscreen preventing solder from making a proper contact. I think it's still possible to use this design by letting solder flow down those pins. But this is substandard and (I assume) not the intent of the design. This issue only affects the right half of the board, as the left half has contacts on the bottom that do not have silkscreen covering them.

I would suggest updating the file to remove the silkscreen from both sides of the microcontroller contacts.

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
 microcontroller contacts preventing soldering.

lpanebr, 2024-01-15:
good to know!

If I'm not mistaken you can prevent this kind of problems by
 - checking the `Subtract soldermask from silkscreen layer` option

on the `plot dialog`:

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

Closed 2024-01-23.

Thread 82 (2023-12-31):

Sweep half-swept halves are not communicating

cfshe, 2023-12-31:
I have recently finished building my sweep half-swept (with two Pro Micro RP2040). I was able to type with both sides for ~1day but then they stopped communicating. The side that is directly plugged into my computer works (and has the correct handedness), but the side connected by the trrs cable (it is trrs) doesn't work. I tried a older qmk version in case any of my edits caused it to break, but it was still broken. I have also plugged both pro micros into a breadbord and checked the RX pin (GPIO1) with micropython, they both were able to read values and write values on the pin.

Any help is appreciated.

cfshe, 2024-01-01:
I forgot to mention, there is continuity between all of the ground pins, RX pins, and VCC pins.

Closed 2024-01-23.

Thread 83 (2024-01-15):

Minor silkscreen issue on Sweep half-swept: SW16 and SW17 misplaced

lpanebr, 2024-01-15:
I haven't printed it yet, but just noticed this.

**In case anyone needs:**
- SW16 and SW17 are misplaced on both layers

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

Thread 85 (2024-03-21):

Question; What type/size of Mill-Max Hotswap Sockets?

Vartroc, 2024-03-21:
Hello,
I was just browsing and searching some materials, when the question arose what type/size of Mill-Max Hotswap Sockets would fit. Maybe I just didn't read carefully enough (I tried) but I can't seem to find any information about that.

I would be delighted if anyone could help me.

duckyb, 2024-03-22:
If you are planning for hotswap why don't you build a sweep bling instead?

Vartroc, 2024-03-23:
You are totally right. I was focusing so hard on trying to find the right Mill-Max Socket, that lost my view of the bigger picture...

Vartroc, 2024-03-23:
Just being curious tho, why is there even the option for a Hotswap Sweep if the Bling exists?

duckyb, 2024-03-23:
> Just being curious tho, why is there even the option for a Hotswap Sweep if the Bling exists?

You mean why is there an option to add millmax sockets to any other sweep? It's because:

1. That option came before the sweep bling was designed
2. To help people that already have a sweep and would like to try hotswap on a budget

Closed 2024-03-23.

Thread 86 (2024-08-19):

Preview not loeading on JLCPCB

adnanaq, 2024-08-19:
Hi,
I am trying to place fabrication order on JLCPCB for sweep bling lp. However, when I load the zip in jlcpc, it doesn't show any image preview of the pcb and doesn't load the dimension. And when trying to add into the after adding the dimensions and required settings manually, it returns `Paramter Exception` error.

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

adnanaq, 2024-08-19:
Tried with Sweep High. Same issue.

adnanaq, 2024-08-19:
Figured it out. I had to run Plot so it could autofill zone and also the drill files are missing from the gerber zip.

jimmyff, 2025-10-01:
Hey @adnanaq I have the same issue, I'm uploading to JLCPCB but all the drill holes appear to be filled in. How did you resolve it?

Thanks!

adnanaq, 2025-10-01:
Also https://forum.kicad.info/t/drill-holes-dont-show-when-printed/21003

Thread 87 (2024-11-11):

The Pro Micro board doesn't seem to be recognized in windows or os x

GregePorter, 2024-11-11:
Hello!

I've assembled Sweep 2 using two Pro Micro boards. I think it looks shipshape and when I plug either side into my Windows machine, it doesn't seem to recognize the boards.

I've tried to look through all the documentation for this, QMK, QMK MSYS and the Pro-micro board to no avail.

I didn't install a reset button though. If I don't have that, is there a way I reset it on the keyboard? I think I saw somewhere the left most or right most key acts as a reset but none of them I've tried seem to do the trick.

EDIT: Sigh, I'm sorry. It was the cable.... the third time was the charm. I'm not quite sure how to reset the keyboard though just the same.

EDIT 2: Ooooh, I misread the directions... I thought it mean the reset switches were optional (not the ones in the parens)

EDIT 3:  Ok, we cool we cool. I (watched this)[https://www.youtube.com/watch?v=HjLx8C5f4mM] which showed how to flash the firmware sans reset button

Closed 2024-11-11.

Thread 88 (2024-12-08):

When I connect them together the sweep isn't detected by laptop

GregePorter, 2024-12-08:
I was able to get the sweep running just fine but it seems like all of a sudden it stopped working.

After some troubleshooting, it seems like the keyboard halves are able to be detected individually by computers and I can flash them but when I connect them together the combined keyboard isn't detected by the computer.

I tried a new cable too. Do you have any ideas about how to troubleshoot that? Should I replace the TRRS Jack?

Thanks!

Update:

Huzzah! It was indeed one or both of the jacks. I kinda did it blindly though. Do you know how I would be able to confirm that it was that using a multimeter?

duckyb, 2024-12-10:
> Do you know how I would be able to confirm that it was that using a multimeter?

It's more likely that it was a soldering issue rather than a faulty TRRS Jack. But you could test them by connecting two jacks with a cable and checking the continuity between the legs of the Jacks.

Closed 2024-12-10.

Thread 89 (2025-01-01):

Missing footprints for Bling MX

BigBLittleS, 2025-01-01:
I'm wanting to adjust the thumb cluster on the Sweep Bling MX.

In kicad I go to update the pcb from schematic I get the following error.

```
Cannot add SW17_r1 (footprint 'Kailh:SW_PG1350_rev_DPB' not found).
Error: Cannot add SW18_r1 (footprint 'Kailh:SW_PG1350_rev_DPB' not found).
...
```

I've searched for this footprint online but I can't find it anywhere.

Where can I get this footprint?

BigBLittleS, 2025-01-01:
Looks like I can alter the position of keys without needing to go through update pcb.

Closed 2025-01-01.

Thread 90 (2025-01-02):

Thank you so much for sharing!

waymond91, 2025-01-02:
I built this 2 or 3 years ago and I take it everywhere with me as my daily driver. I have had some ergonomic issues in the past and this has been a huge help 🚀

Closed 2025-01-02.

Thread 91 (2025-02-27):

Why only TRRS cable?

jakobkhansen, 2025-02-27:
Hi, I'm looking to understand why I cannot use a TRS cable with this board. From my understanding and from a QMK perspective, if you use a serial communication driver, it will only use three pins on the TRRS jack, and therefore it should work with a TRS cable. I have a Corne keyboard which works fine with a TRS cable, so I'm wondering what the difference is for the Sweep? I have not had any luck with using a serial driver and a TRS cable, only TRRS cable works.

gromms, 2025-05-07:
I was wondering the same thing but it looks like the pcb is designed so that TRS cable would short Vcc straight to ground so make sure you never use TRS cable when you have the board powered up. There does not seem to be any reason why it should be designed this way and you are right, only three pins of TRRS are used.

If the pins were swapped so that the S and R2 were GND or if S was not connected anywhere, then TRS cable should also work.

davidphilipbarr, 2025-05-08:
It's a fair point, I think the idea was to theoretically reduce the chance
of shorting. If someone submitted an update I'd apply it but other than
that it is what it is now I guess :)

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

duckyb, 2025-05-08:
Turned this question into a feature request, anyone is welcome to work on this.

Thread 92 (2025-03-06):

Create gerber files for top plates

DusanLesan, 2025-03-06:
As mentioned here [#76](https://github.com/davidphilipbarr/Sweep/issues/76#issuecomment-2691141273), I would like to request for gerber files that would be used at online services like jlcpcb to create top plates for sweep boards.
I am facing an issue on my Sweep Bling LP where hot-swap sockets are not gripping on my Kailh switches strong enough.
To prevent this, I would need to have a top plate and my preference is for that to be FR4 over 3D printed ones but even 3D print files would do.

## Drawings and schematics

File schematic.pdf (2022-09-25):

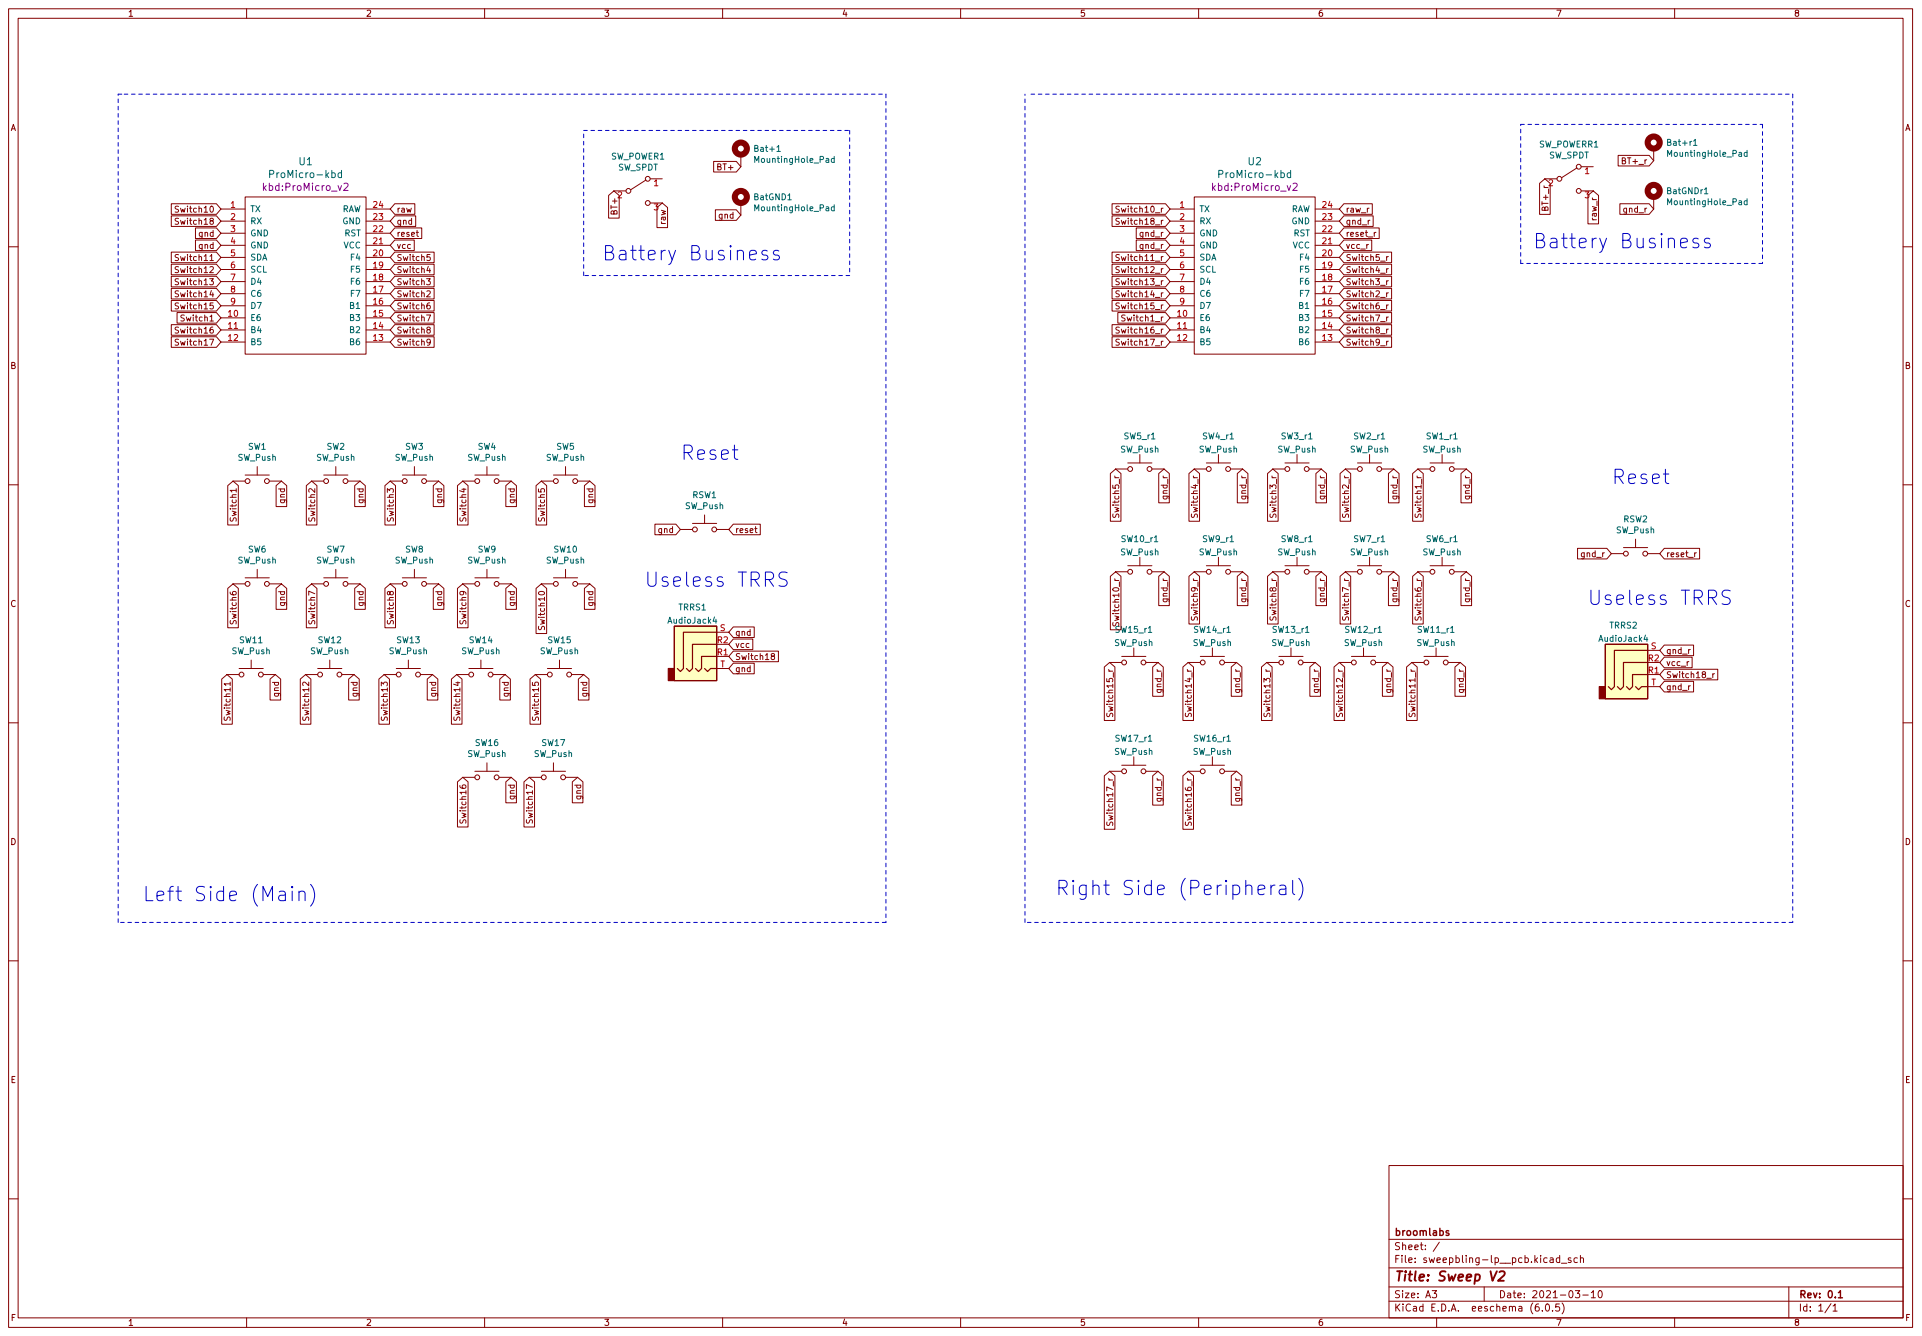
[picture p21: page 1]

File: sweepbling-lp__pcb.kicad_sch Sheet: / broomlabs

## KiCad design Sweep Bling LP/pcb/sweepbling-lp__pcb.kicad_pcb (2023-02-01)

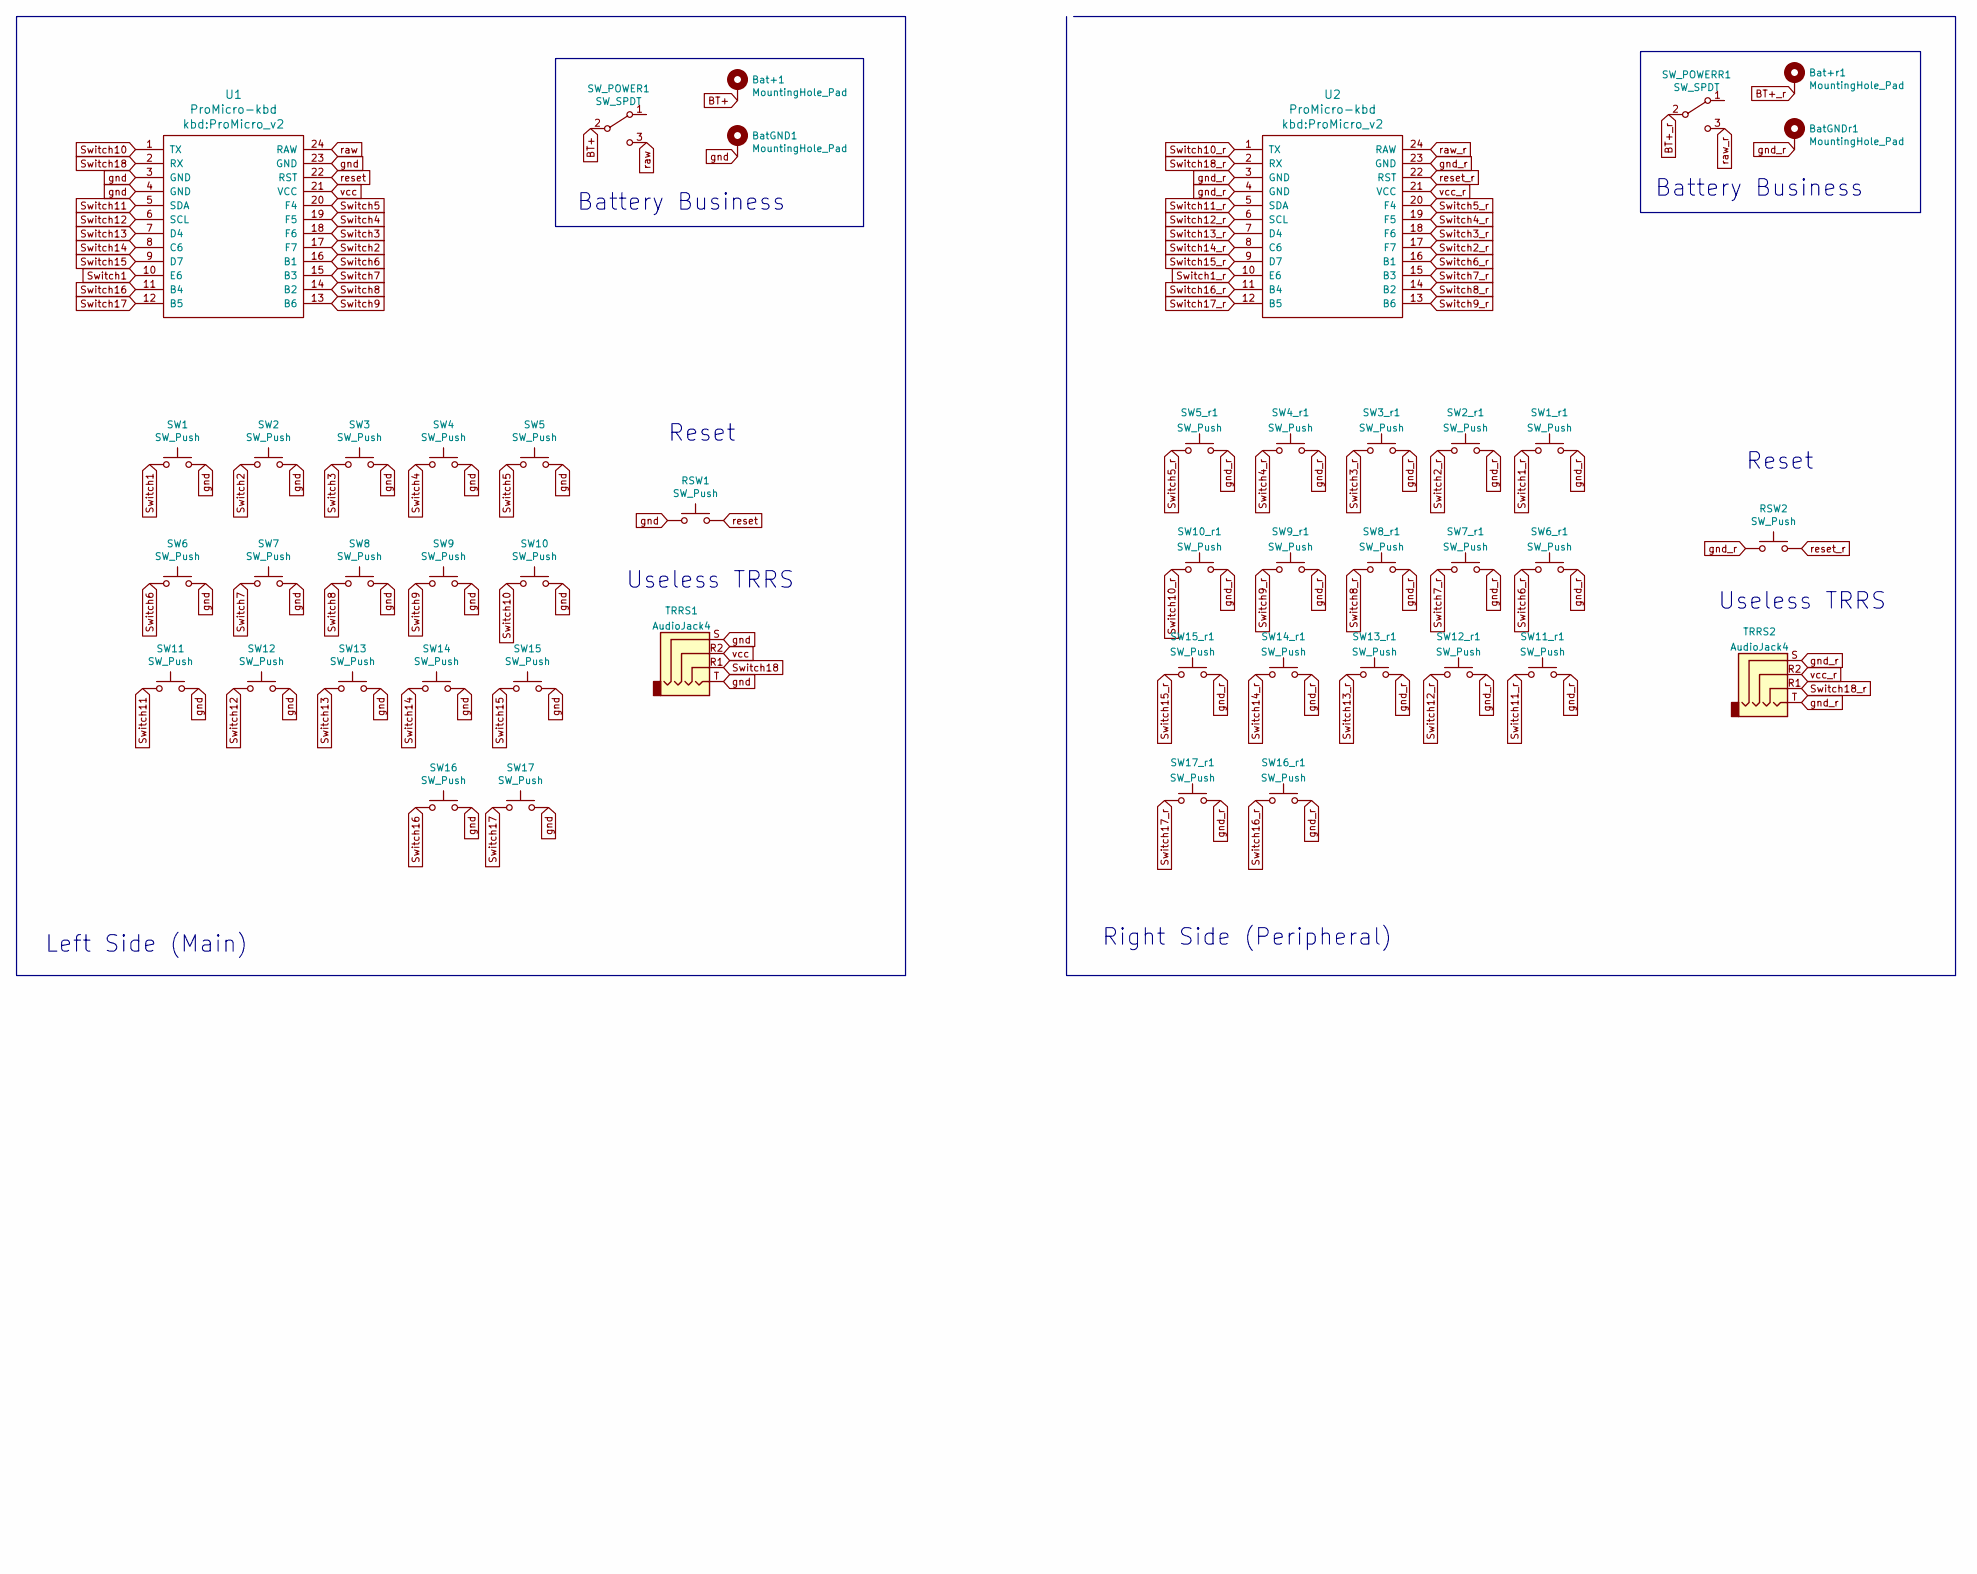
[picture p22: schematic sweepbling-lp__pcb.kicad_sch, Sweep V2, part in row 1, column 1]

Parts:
Bat+1: MountingHole_Pad; 1pin_conn
Bat+r1: MountingHole_Pad; 1pin_conn
BatGND1: MountingHole_Pad; 1pin_conn
BatGNDr1: MountingHole_Pad; 1pin_conn
RSW1, RSW2: SW_Push; ResetSW
SW1, SW1_r1, SW2, SW2_r1, SW3, SW3_r1, SW4, SW4_r1, SW5, SW5_r1, SW6, SW6_r1, SW7, SW7_r1, SW8, SW8_r1, SW9, SW9_r1, SW10, SW10_r1, SW11, SW11_r1, SW12, SW12_r1, SW13, SW13_r1, SW14, SW14_r1, SW15, SW15_r1, SW16, SW16_r1, SW17, SW17_r1: SW_Push; SW_PG1350_rev_DPB
SW_POWER1: SW_SPDT; SPDT_C128955
SW_POWERR1: SW_SPDT; SPDT_C128955
TRRS1, TRRS2: AudioJack4
U1, U2: ProMicro-kbd; ProMicro_v2

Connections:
BT+: Bat+1.1, SW_POWER1.2 (B)
BT+_r: Bat+r1.1, SW_POWERR1.2 (B)
Switch1: SW1.1, U1.10 (E6)
Switch1_r: SW1_r1.1, U2.10 (E6)
Switch2: SW2.1, U1.17 (F7)
Switch2_r: SW2_r1.1, U2.17 (F7)
Switch3: SW3.1, U1.18 (F6)
Switch3_r: SW3_r1.1, U2.18 (F6)
Switch4: SW4.1, U1.19 (F5)
Switch4_r: SW4_r1.1, U2.19 (F5)
Switch5: SW5.1, U1.20 (F4)
Switch5_r: SW5_r1.1, U2.20 (F4)
Switch6: SW6.1, U1.16 (B1)
Switch6_r: SW6_r1.1, U2.16 (B1)
Switch7: SW7.1, U1.15 (B3)
Switch7_r: SW7_r1.1, U2.15 (B3)
Switch8: SW8.1, U1.14 (B2)
Switch8_r: SW8_r1.1, U2.14 (B2)
Switch9: SW9.1, U1.13 (B6)
Switch9_r: SW9_r1.1, U2.13 (B6)
Switch10: SW10.1, U1.1 (TX)
Switch10_r: SW10_r1.1, U2.1 (TX)
Switch11: SW11.1, U1.5 (SDA)
Switch11_r: SW11_r1.1, U2.5 (SDA)
Switch12: SW12.1, U1.6 (SCL)
Switch12_r: SW12_r1.1, U2.6 (SCL)
Switch13: SW13.1, U1.7 (D4)
Switch13_r: SW13_r1.1, U2.7 (D4)
Switch14: SW14.1, U1.8 (C6)
Switch14_r: SW14_r1.1, U2.8 (C6)
Switch15: SW15.1, U1.9 (D7)
Switch15_r: SW15_r1.1, U2.9 (D7)
Switch16: SW16.1, U1.11 (B4)
Switch16_r: SW16_r1.1, U2.11 (B4)
Switch17: SW17.1, U1.12 (B5)
Switch17_r: SW17_r1.1, U2.12 (B5)
Switch18: TRRS1.R1, U1.2 (RX)
Switch18_r: TRRS2.R1, U2.2 (RX)
gnd: BatGND1.1, RSW1.1, SW1.2, SW2.2, SW3.2, SW4.2, SW5.2, SW6.2, SW7.2, SW8.2, SW9.2, SW10.2, SW11.2, SW12.2, SW13.2, SW14.2, SW15.2, SW16.2, SW17.2, TRRS1.S, TRRS1.T, U1.3 (GND), U1.4 (GND), U1.23 (GND)
gnd_r: BatGNDr1.1, RSW2.1, SW1_r1.2, SW2_r1.2, SW3_r1.2, SW4_r1.2, SW5_r1.2, SW6_r1.2, SW7_r1.2, SW8_r1.2, SW9_r1.2, SW10_r1.2, SW11_r1.2, SW12_r1.2, SW13_r1.2, SW14_r1.2, SW15_r1.2, SW16_r1.2, SW17_r1.2, TRRS2.S, TRRS2.T, U2.3 (GND), U2.4 (GND), U2.23 (GND)
raw: SW_POWER1.3 (C), U1.24 (RAW)
raw_r: SW_POWERR1.3 (C), U2.24 (RAW)
reset: RSW1.2, U1.22 (RST)
reset_r: RSW2.2, U2.22 (RST)
vcc: TRRS1.R2, U1.21 (VCC)
vcc_r: TRRS2.R2, U2.21 (VCC)

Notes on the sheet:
Battery Business
Useless TRRS
Reset
Left Side (Main)
Right Side (Peripheral)

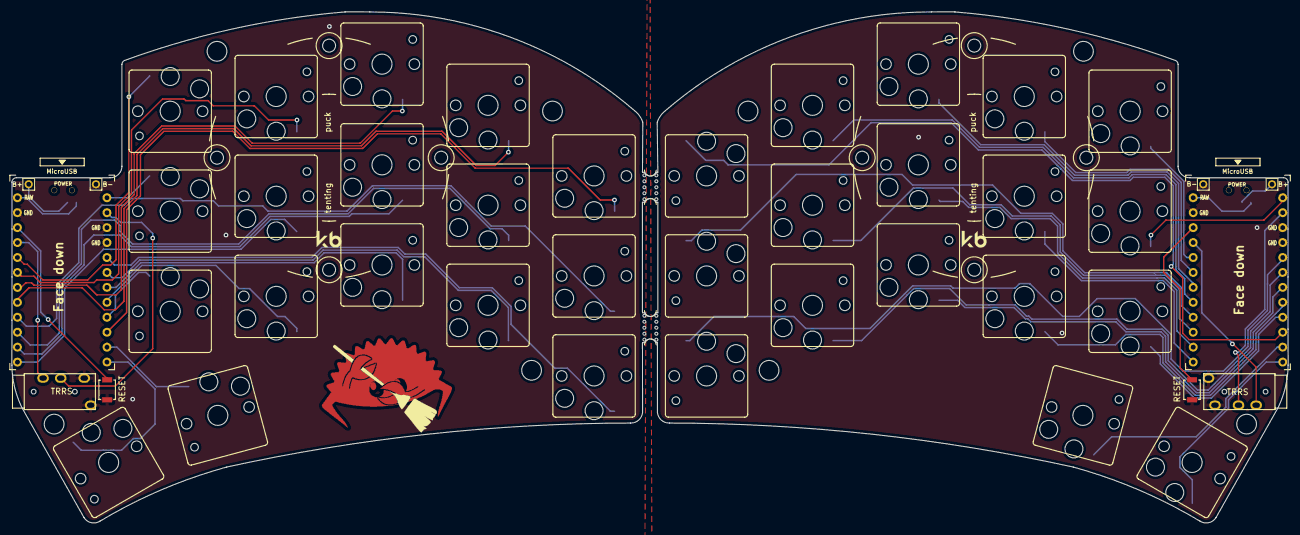
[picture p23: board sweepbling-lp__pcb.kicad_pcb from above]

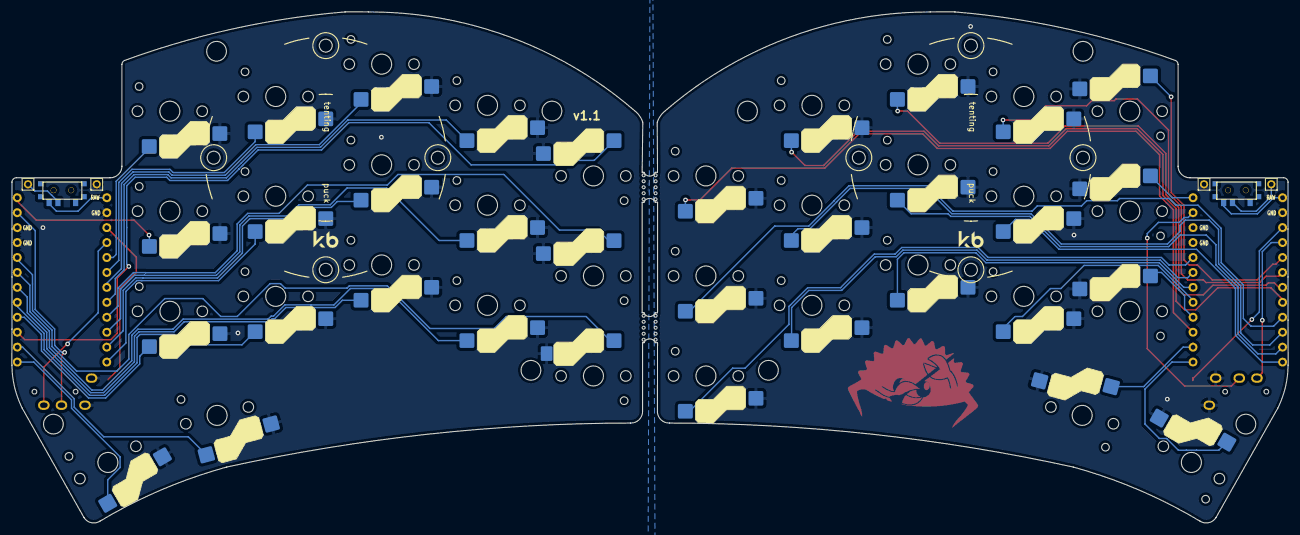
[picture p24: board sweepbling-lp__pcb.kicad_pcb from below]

Board: 2 copper layers, 216.9 x 86.9 mm, 51 parts (2 on the bottom side), 46 nets.

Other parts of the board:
REF_PUCK_R: Tenting Puck; Tenting_Puck2_no_pads
SweepLogo: LOGO; ferris_broom
e: Tenting Puck; Tenting_Puck2_no_pads
mouse-bite-2mm-slot1, mouse-bite-2mm-slot2: VAL**; mouse-bite-5mm-slot-with-space-for-track

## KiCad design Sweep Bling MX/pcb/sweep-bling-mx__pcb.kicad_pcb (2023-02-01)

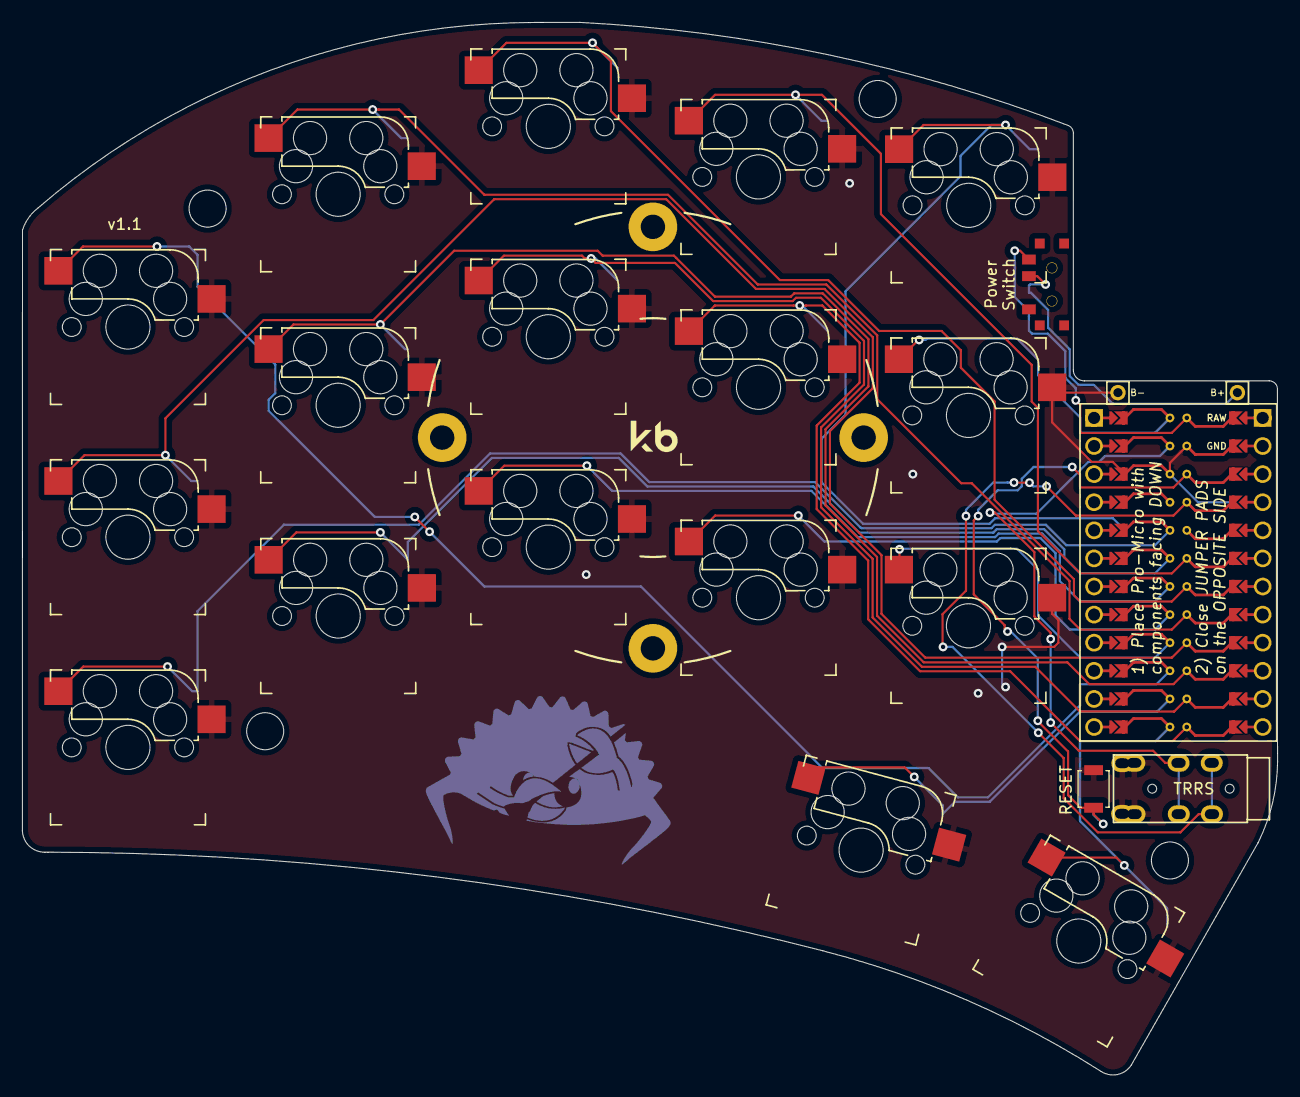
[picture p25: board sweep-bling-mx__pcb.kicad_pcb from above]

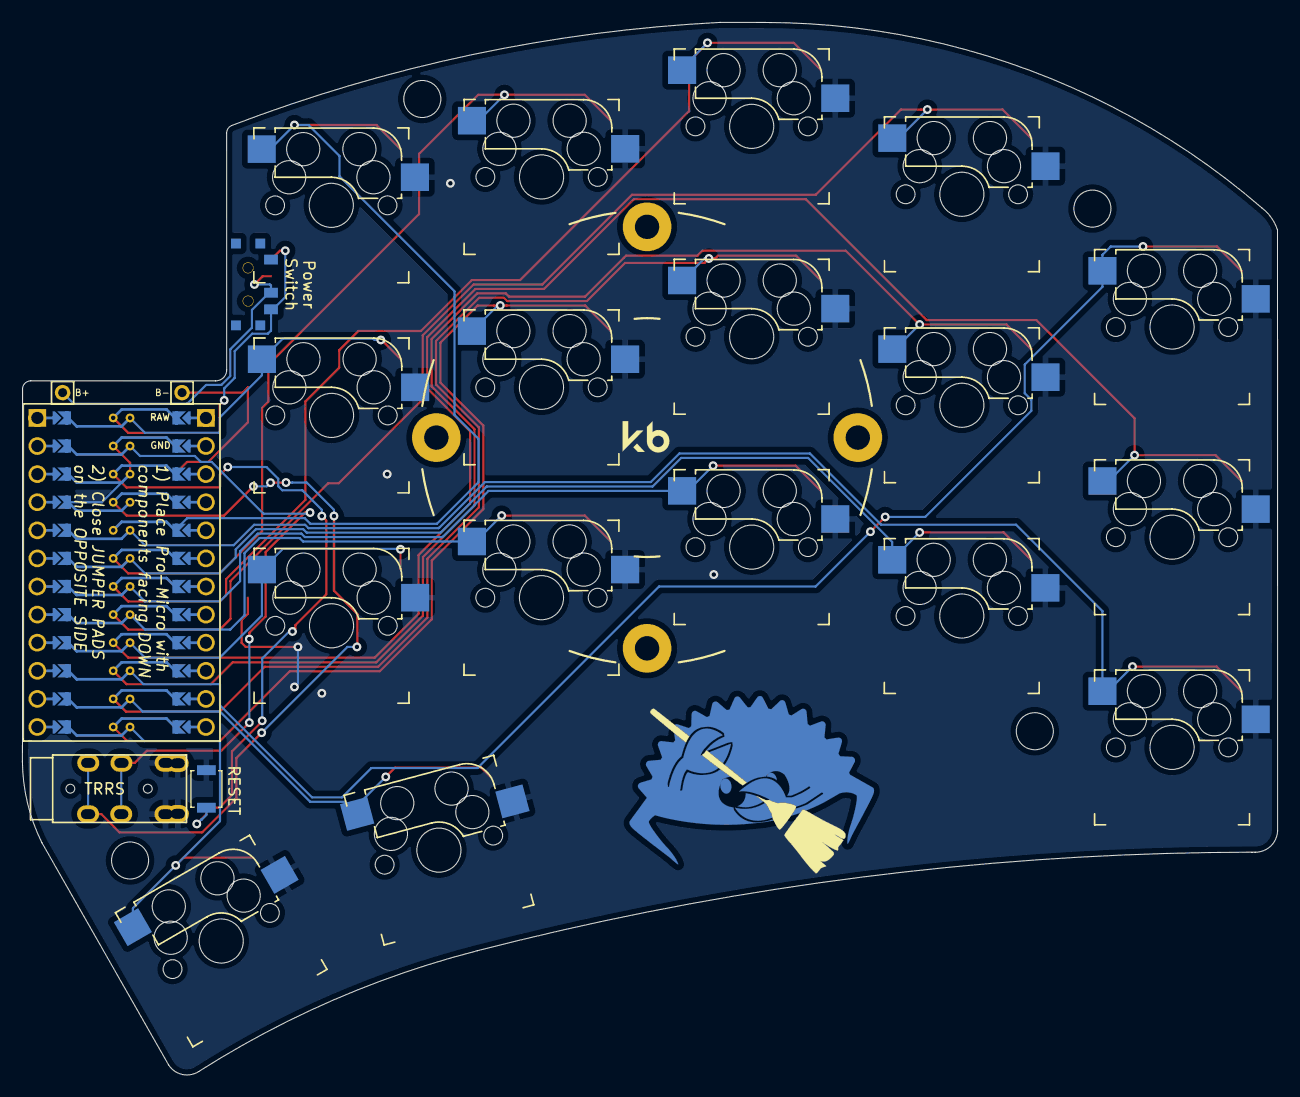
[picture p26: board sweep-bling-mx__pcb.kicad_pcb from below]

Board: 2 copper layers, 113.5 x 95.2 mm, 29 parts (2 on the bottom side), 23 nets.

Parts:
Bat+r1: MountingHole_Pad; 1pin_conn
BatGND1: MountingHole_Pad; 1pin_conn
J2: AudioJack4dpb; TRRS-PJ-DPB2
Mounting 01, Mounting 02, Mounting 03, Mounting 04: MountingHole_3.35mm
RST_B: SW_Push; SW_SPST_B3U-1000P
RST_F: SW_Push; SW_SPST_B3U-1000P
SW2, SW3, SW4, SW5, SW6, SW8, SW9, SW10, SW11, SW12, SW14, SW15, SW16, SW17, SW18, SW20, SW21: SW_Push; Kailh_socket_MX_reversible_sameside
SW_POWERR1: SW_SPDT; SPDT_C128955
SW_POWERR_BK: SW_SPDT; SPDT_C128955r
U1: ProMicro-kbd; ProMicro_facedown

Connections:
BT+_r: Bat+r1.1, SW_POWERR1.2, SW_POWERR_BK.2
Switch1: SW2.1, U1.10
Switch2: SW3.1, U1.17
Switch3: SW4.1, U1.18
Switch4: SW5.1, U1.19
Switch5: SW6.1, U1.20
Switch6: SW8.1, U1.16
Switch7: SW9.1, U1.15
Switch8: SW10.1, U1.14
Switch9: SW11.1, U1.13
Switch10: SW12.1, U1.1
Switch11: SW14.1, U1.5
Switch12: SW15.1, U1.6
Switch13: SW16.1, U1.7
Switch14: SW17.1, U1.8
Switch15: SW18.1, U1.9
Switch16: SW21.1, U1.11
Switch17: SW20.1, U1.12
Switch18: J2.R1, U1.2
gnd: BatGND1.1, J2.S, J2.T, RST_B.1, RST_F.1, SW2.2, SW3.2, SW4.2, SW5.2, SW6.2, SW8.2, SW9.2, SW10.2, SW11.2, SW12.2, SW14.2, SW15.2, SW16.2, SW17.2, SW18.2, SW20.2, SW21.2, U1.3, U1.4, U1.23
raw: SW_POWERR1.3, SW_POWERR_BK.3, U1.24
reset: RST_B.2, RST_F.2, U1.22
vcc: J2.R2, U1.21

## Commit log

2020-11-24 Hello new sweep home
    [ferris-sweep-compact.dsn, ferris-sweep-compact.kicad_pcb, ferris-sweep-compact.sch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]
2020-12-09 update gerber
2021-01-22 update stagger and routing
    [ferris-sweep-compact.kicad_pcb, ferris-sweep-compact.sch]
2021-01-22 update stagger
    [ferris-sweep-compact.kicad_pcb]
2021-02-08 Add controller directional hint to pcb as well.
    [ferris-sweep-compact.kicad_pcb]
2021-05-07 Add version 2 of sweep, untested, may be dragons.
    [sweepv2.kicad_pcb, sweepv2.sch]
2021-05-07 bom comment changes
    [sweepv2.kicad_pcb]
2021-05-07 better switch placement but still actually all over, don't use.
    [sweepv2.kicad_pcb]
2021-05-08 better alignment?
    [sweepv2.kicad_pcb]
2021-07-26 pcbs are flip-able for optional up-facing controllers, add top plate
    allow the pcbs to be flipped so you can use a bugger battery under nice!nano (potentially) add top plate.
    Untested...
    [sweepv2.kicad_pcb, sweepv2_plate.kicad_pcb]
2021-07-27 resets and trrs
    [sweepv2.kicad_pcb]
2021-07-28 remove all the reversible bits
    back to one sided.
    [sweepv2.kicad_pcb]
2021-08-03 flippable version of sweep2
    Useful for allpcb, some larger battery use cases, etc. generally a waste of time, use sweep2.
    [half-swept.kicad_pcb, half-swept.sch]
2021-09-10 remove pointless trace
    [half-swept.kicad_pcb]
2021-09-13 First upload of mx/choc2/alps version.
    Here there be dragons.
    [sweep-high.kicad_pcb, sweep-high.sch]
2021-09-21 fix vcc tidy up routing
    [sweep-high.kicad_pcb]
2021-10-27 add power switch part number, thanks Cem Aksoylar!
2021-11-04 Add comparison chart
    Reduce user confusion in picking the correct device with a comparison chart. Description texts are also updated and the Sweep HIGH is added.
2021-11-04 Remove reversible PCB from Sweep High
2021-11-15 add gerber from Karl, that should work.
2021-11-15 add tentative 2.1
    [sweepv2.1.kicad_pcb, sweepv2.1.sch, sweepv2.1_plate.kicad_pcb]
2021-11-19 superflous routing.
    [sweep-compact-ble.kicad_pcb, sweep.kicad_pcb]
2021-11-19 Refactor repository and fix breakaway tabs
    [ferris-sweep-compact.kicad_pcb, ferris-sweep-compact.sch, half-swept.kicad_pcb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]
2021-11-20 Add gerbers
    [sweep-high.kicad_pcb, sweepv2.1.kicad_pcb]
2021-11-22 replace reversible switch footprint
    [sweepv2.kicad_pcb]
2021-11-26 doc(sweepv2.1): Added PCB ordering values to README
2021-11-27 fix(pr-feedback): Added PCB ordering to Sweep 2 and HIGH READMEs
2021-11-29 Update gerbers and add gitignore
    [sweepv2.1.kicad_pcb, sweepv2.kicad_pcb]
2021-12-06 simplified sweep high for all pcb usage
    Half a sweep high.
    [sweep-high.kicad_pcb, sweep-high.sch]
2021-12-21 Update silk and edge cuts
    [half-swept.kicad_pcb]
2021-12-21 Remove B5 label and update gerber
    [half-swept.kicad_pcb]
2021-12-21 Add optional top plate files
    [sweep-high-top-plate.dxf]
2022-01-16 Create sweep bling mx
    [sweep-bling-mx__bottom.kicad_pcb, sweep-bling-mx__pcb.kicad_pcb, sweep-bling-mx__pcb.sch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]
2022-01-17 Update silk and MCU orientation
    [sweep-bling-mx__pcb.kicad_pcb, sweep-bling-mx__pcb.sch]
2022-01-17 Run auto router
    [sweep-bling-mx__pcb.kicad_pcb]
2022-01-17 Flip MCU pads for face down and re-route
    [sweep-bling-mx__pcb.kicad_pcb]
2022-01-18 Add partial manual routing
    [sweep-bling-mx__pcb.kicad_pcb]
2022-01-18 Finish manual routing
    [sweep-bling-mx__pcb.kicad_pcb]
2022-01-18 Fix DRC issues
    [sweep-bling-mx__pcb.kicad_pcb]
2022-01-18 Update readmes and gerbers
    [sweep-bling-mx__bottom.kicad_pcb, sweep-bling-mx__pcb.kicad_pcb, sweep-bling-mx__pcb.sch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]
2022-01-18 Add kailh sockets to readme
2022-01-29 add plate pcb files
    [sweep-high_plate.kicad_pcb]
2022-02-13 Add switch plate xdf
    [sweep-bling-mx__plate.dxf]
2022-02-13 Update version number on PCB (v1.0)
    [sweep-bling-mx__pcb.kicad_pcb]
2022-02-13 Remove pre-release warnings
    [sweep-bling-mx__bottom.kicad_pcb, sweep-bling-mx__pcb.kicad_pcb, sweep-bling-mx__pcb.sch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]
2022-02-15 Archive sweep 2.0
    [sweepv2.kicad_pcb, sweepv2.sch, sweepv2_plate.kicad_pcb]
2022-03-29 Remove alignment target from Bling MX
    [sweep-bling-mx__bottom.kicad_pcb]
2022-04-24 Enlarge slots to .5mm
    [sweep-high.kicad_pcb]
2022-04-24 Fix silk screen
    [sweep-high.kicad_pcb]
2022-04-24 Fix DRC issues on edge
    [sweep-high.kicad_pcb]
2022-04-25 Fix tracks and update gerber
    [sweep-high.kicad_pcb]
2022-05-01 Add support for millmax sockets
    [sweepv2.1.kicad_pcb, sweepv2.kicad_pcb, sweepv2.sch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]
2022-05-01 Update gerber version in README
2022-05-09 Fix PCB measurements
2022-05-10 Fix for issue#39
    [sweep-bling-mx__plate-Edge_Cuts.dxf, sweep-bling-mx__plate-lasercut.dxf, sweep-bling-mx__plate.dxf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]
2022-05-10 Remove accidentally added bling lp plate
    [sweepbling-lp__plate-Edge_Cuts.dxf, sweepbling-lp__plate.kicad_pcb]
2022-05-15 Add Sweep Bling LP PCB
    [sweepbling-lp__pcb.kicad_pcb, sweepbling-lp__pcb.sch]
2022-05-15 Fix schematic
    [sweepbling-lp__pcb.kicad_pcb, sweepbling-lp__pcb.kicad_sch]
2022-05-15 Add gerber
2022-05-17 Update board preview
2022-05-17 Fix bling mx malformed outline
    [sweep-bling-mx__pcb.kicad_pcb]
2022-05-17 Fix DRC on sweep high m
    [sweep-high.kicad_pcb]
2022-05-17 Update bottom plate malformed edge cuts
    [sweep-bling-mx__bottom.kicad_pcb]
2022-05-17 Update all READMEs, Add pcbdraw output
2022-05-18 Update pcbdraw theme
2022-05-18 Use blue pcb for previews
2022-05-18 Update bling mx fill zones
    [ferris-sweep-compact.dsn, ferris-sweep-compact.kicad_pcb, ferris-sweep-compact.sch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]
2022-05-18 Revert "Update bling mx fill zones"
    This reverts commit 3a15cb16145cf41150a782c0904b577e07dc4e4a.
    [ferris-sweep-compact.dsn, ferris-sweep-compact.kicad_pcb, ferris-sweep-compact.sch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]
2022-05-18 Update sweep half swept
    [half-swept.kicad_pcb, half-swept.kicad_sch, half-swept.sch]
2022-05-18 Add RAW/GND label, update gerber.zip
    [half-swept.kicad_pcb]
2022-05-19 Update compact low
    [ferris-sweep-compact.kicad_pcb, ferris-sweep-compact.kicad_sch, ferris-sweep-compact.sch]
2022-05-25 Update bling-lp pcb
    [sweepbling-lp__pcb.kicad_pcb]
2022-09-02 Update Sweep naming system
    [ferris-sweep-compact.dsn, half-swept.kicad_pcb, half-swept.kicad_sch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]
2022-09-25 Add PDF of the schematic
2022-11-17 Fix Bling-MX plate file & gerber
2023-02-01 Update Bling LP spacer hole diameter & gerber
    [sweepbling-lp__pcb.kicad_pcb]
2023-02-01 Update Bling MX spacer hole diameter, silk & gerber
    [sweep-bling-mx__pcb.kicad_pcb]
2024-01-23 Fixes #81 adds plate
    [sweep-high.kicad_pcb, sweep-high_plate.kicad_pcb]
